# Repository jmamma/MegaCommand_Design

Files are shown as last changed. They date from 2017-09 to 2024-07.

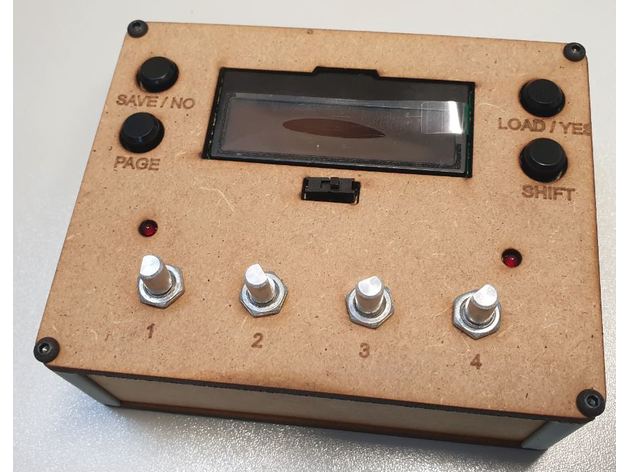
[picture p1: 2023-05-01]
Enclosure/MegaCommand_DIY/Router Design/images/20221028_100851.jpg

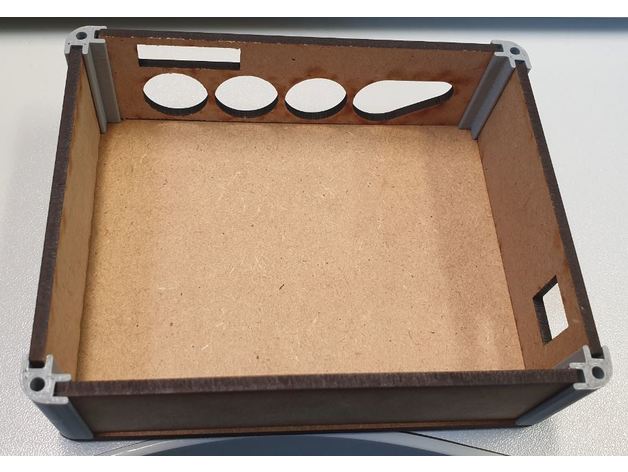
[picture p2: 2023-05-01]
Enclosure/MegaCommand_DIY/Router Design/images/20221028_100230.jpg

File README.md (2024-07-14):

# MegaCommand

## Description:

The MegaCommand is an open-source MIDI controller that runs the MCL firmware for use with the Elektron Machinedrum.
It is is based around the Arduino Mega 2560.

The printed cicuit board is a through-hole design (no SMD soldering skills required). 

* 4 x MIDI ports (2 in, 2 out)
* 4 x Rotary Encoders + Push button
* 4 x Buttons
* 1 x OLED display
* SD Card
* 128KBytes of SRAM (0-63KB accessible natively, 64-128KB accessible with bank selection)
* 2 x 10pin Expansion ports

Stack is 8KB in size. 
56KB of SRAM reserved for global objects, variables. (bank switchable)

The MCL respository contains the software component of this project.
https://github.com/jmamma/MCL

## Project Status:

Board revision: 1_0_2a12

__ALL INFORMATION BELOW IS PROVIDED AS A CONVENIENCE AND COULD BE SUBJECT TO ERROR OR CHANGE.__

## Bill of Materials:

1.0.2a:
https://github.com/jmamma/MegaCommand_Design/blob/master/1_0_2/bill_of_materials

## Display

OLED 128x32, it uses the SPI bus.

Important: OLED display requires resistor position changes to enable SPI mode as per adafruit documentation 
https://learn.adafruit.com/2-3-monochrome-128x32-oled-display-module/assembly-1):

## PCB Fabrication:

You can easily get your own PCBs made.

[PCBWay.com fabrication options](https://github.com/jmamma/MegaCommand_Design/blob/master/pcb_fabrication_preferences.jpg)

Gerber files (pcb layout diagrams used for fabrication) are included in the ./gerber/ directory above.

Download gerbers and submit to PCB manufacturer.

Circuit Schematic and Board Layout is present in Eagle files.

## Enclosure:

1.0.2a:

The enclosure can be 3D printed. The design files and variations are located in:

https://github.com/jmamma/MegaCommand_Design/tree/master/Enclosure/OLED/3D

Optionally print 4 spacers and superglue to the screw holes on the OLED to ease
installation of the screen at the proper height.

## Build Instructions

The build is organised in to multiple stages. You must follow the order sequentially.
At the end of each stage there is a test checkpoint. It is important that you perform these tests to ensure
each stage is working before proceeding to the next, failing to do so will make troubleshooting any problems much harder.

```
VERIFY CHIP ORIENTATION BEFORE SOLDERING.

OLED display must be installed last.

Take care in making sure the ICs are inserted the correct way around.

## Build Order: 

  1. ICS: RAM, Octal Latch, Shift Registers
  2. Arduino male headers. 
  3. Capacitors. (Make sure the 220uF electrolytic cap fits when the arduino is connected)
                 (10uF +ve terminal is soldered to pad closest to SD card holder.
                 
TEST POINT: Run the SRAM firmware test.

  4. MEC switches (Make sure these sit completely flush with the board and are not leaning to one side)
  5. Resistor arrays
  6. Encoders (Make sure these sit completely flush with the board and are not leaning to one side)  
  
TEST POINT: Run the button and encoder test firmware.
  7. ICS: MIDI Optocouplers. 
  8. Resistors + diodes
  9. MIDI DIN ports.
 
TEST POINT: Run the MIDIPort test firmware.

 10. Power Jack (+9V tip)
 11. Yamaichi SD card holder.
     
TEST POINT: Insert SD Card, Run the SDCARD test firmware
 
OLED Display:
 12. Oled display requires correct resistor poisiton in order to be configured for SPI mode. (See documentation above to confirm the resistor placement)
 13. Male header to be soldered to OLED board. Header is then soldered on to MegaCommand PCB. The height of the OLED display is important. The distance between the mainboard pcb, and the bottom on the OLED pcb should be 5mm when soldered.
 
 14. LEDs (+ anode pin nearest to the bottom of the board for both LEDs. ). When soldered, the tip of the LED should measure 11mm above mainboard pcb.
 
 15. Power switch. (optional, you can solder a short between the two right most pins on EG1212B  
 
 Expansion Headers:
 
 16. These are short 5mm headers. It might not be possible to buy them at the right length so you'll need to cut them down to 10 pin.
 
TEST POINT: Run the LCD and LED test firmware.

## Important

OLED Display must be installed last.

5) To install the male headers that connect to the MegaCommand to the ArduinoMega, insert the headers in to the ArduinoMega then solder with the arduino attached to the headers. This will ensure perfect alignment.
```

## Firmware

Once you've built a MegaCommand you can upload the latest version of the  MCL firmware located here: 
https://github.com/jmamma/MCL/releases

If you're familiar with coding you can write sketches within the Arduino IDE to test the hardware and run custom firmwware.
Before you start coding you need to decide which core you are going to use.

## Arduino Cores
In ArduinoIDE, a Core is a collection of initialisation functions and associated libraries, used for configuring the underlying hardware; it is analogous to an Operating System kernel.

The cores availabile in the Arduino IDE are listed under Tools -> Boards.

Arduino Mega or Mega 2560:

This is the standard core that comes installed default with the Arduino IDE. If you use this core with the MegaCommand you can program the MegaCommand like an ordinary arduino shield. The built in arduino functions can be used to control the hardware using the pin assignement detailed below.

MCL Core:

This was built on top of Manuel Odendahl's core for the MiniCommand.
By using this core you can take advantage of the powerful MIDI libraries and GUI functionality.

For example, the MegaCommand core is necessary for running the MCL firmware, and controlling the Elektron instrument range.

### Installing the MCL core.
(Instructions for OSX, should be similar for Windows)

1) Download the Arduino IDE https://www.arduino.cc/en/Main/Software (1.8.5 tested)

2) Get the MIDICtrl library and MegaCommand Core (same repo):
```
   cd /Applications/Arduino.app/Contents/Java/hardware/
   git clone https://github.com/jmamma/MCL
```
### Selecting the Core

1) Open the Arduino IDE, Under the Tools menu, select the core you wish to use from the "Board:" menu

The default Arduino core is named "Arduino/Genuino Mega or Mega 2560"

The MegaCommand core will be listed at the bottom. 

## MegaCommand vs MiniCommand

The MegaCommand shield was designed to be backwards compatible with the original MiniCommand hardware. 

However, there are notable differences between the two systems, including new pin assignments which must be taken account for when using the original MidiCtrl libraries.

The original MiniCommand used the ATMega64 microprocessor whilst the MegaCommand Shield is built on top of ArduinoMega which uses the ATMega2560 processor. The ATMega2560 shares most of the IO functionality of the ATMega64 but has additional pins, and a different pin-to-port layout.

The MegaCommand Shield accesses the ATMega2560 processor on board the ArduinoMega through the exposed headers, not all pins on the ATMega2560 are exposed through this Arduino interface.

Incorporating the differences between both processors and subsequent pin availability the following pin assignment has been made as the best possible substitutes for the original hardware layout.

```
4 Midi Ports vs 3
256k ROM vs 64K
USB vs No USB

--

MegaCommand pin changes from original MiniCommand are as followed:

MicroSD board:

CS = PB0

SRAM

BankSel = PL6

Key Scanning (Shift Register Circuit):

PL0 = OUT
PL1 = SHIFT
PL2 = CLK

HD44780 LCD Circuit:

E = PL4
R/S = PL3

LEDs:

PE5 = LED0
PE4 = LED1

MIDI:

TXD0 and RXD0 (USART0) are reserved for Arduino USB interface.

Therefore we shift midi ports by 1.

MIDI Port 1:

RXD1 = MIDI Port 1 IN.
TXD1 = MIDI Port 1 OUT

Midi Port 2:

RXD2 = MIDI Port 2 IN
TXD2 = MIDI Port 2 OUT ( New port, not available on original Minicommand)
```

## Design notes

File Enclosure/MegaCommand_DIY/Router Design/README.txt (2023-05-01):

Megacommand Case by Pabloantxon on Thingiverse: https://www.thingiverse.com/thing:5591808

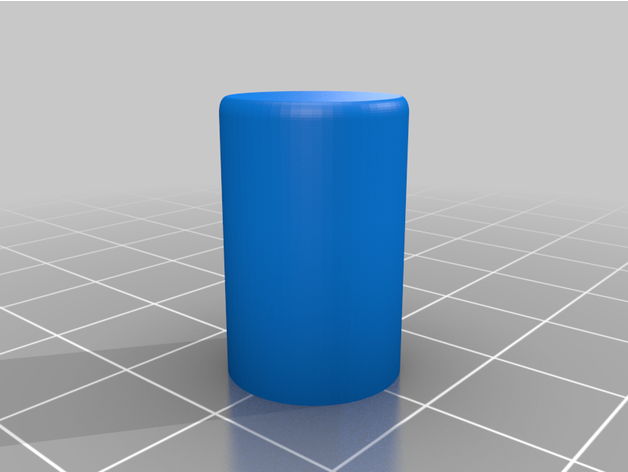
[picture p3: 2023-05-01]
Enclosure/MegaCommand_DIY/Router Design/images/knob.png

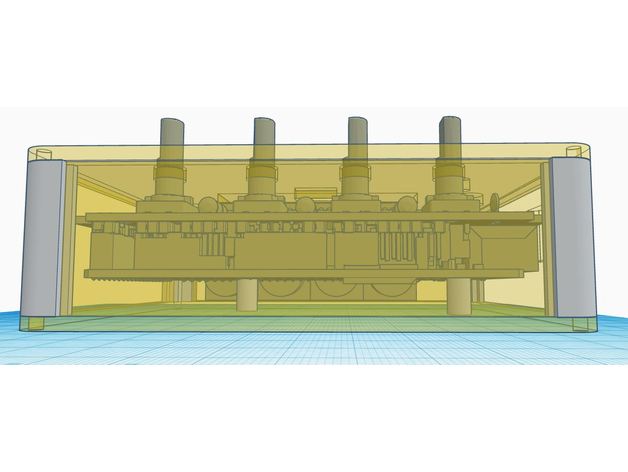
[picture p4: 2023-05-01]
Enclosure/MegaCommand_DIY/Router Design/images/3D3.JPG

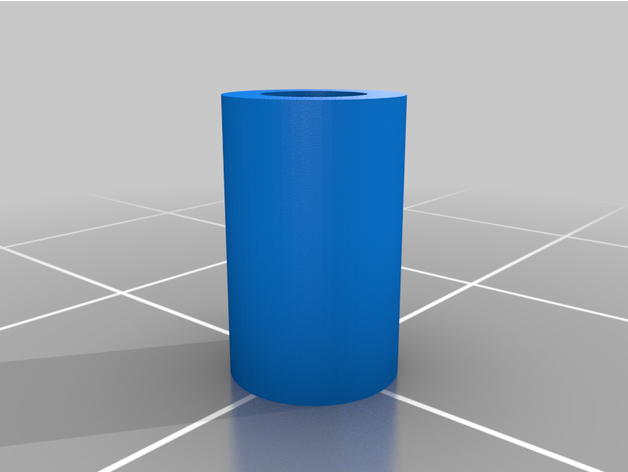
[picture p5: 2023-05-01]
Enclosure/MegaCommand_DIY/Router Design/images/ArduinoStand.png

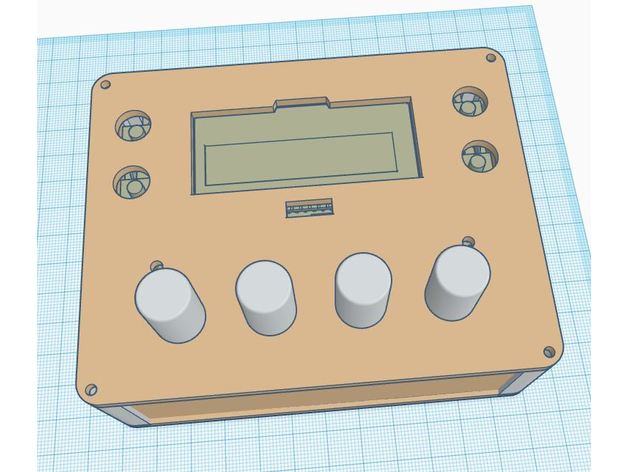
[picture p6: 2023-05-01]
Enclosure/MegaCommand_DIY/Router Design/images/3D4.JPG

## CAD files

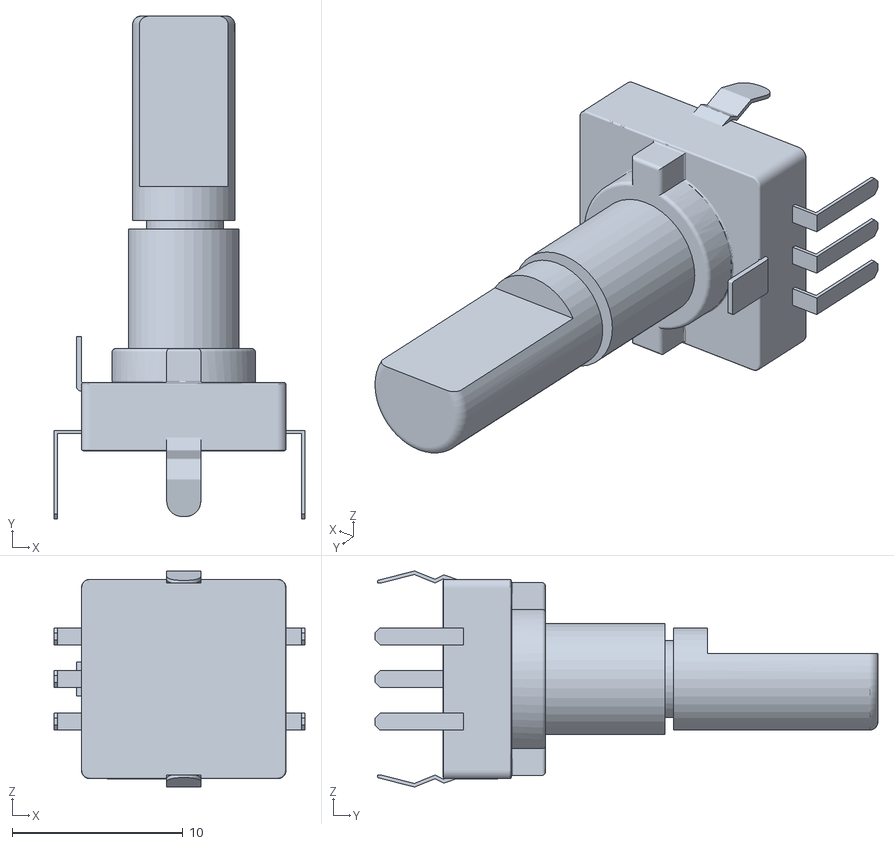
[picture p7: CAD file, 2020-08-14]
Assembly_Models/alps_encoder.STL
14.7 x 29.5 x 12.7

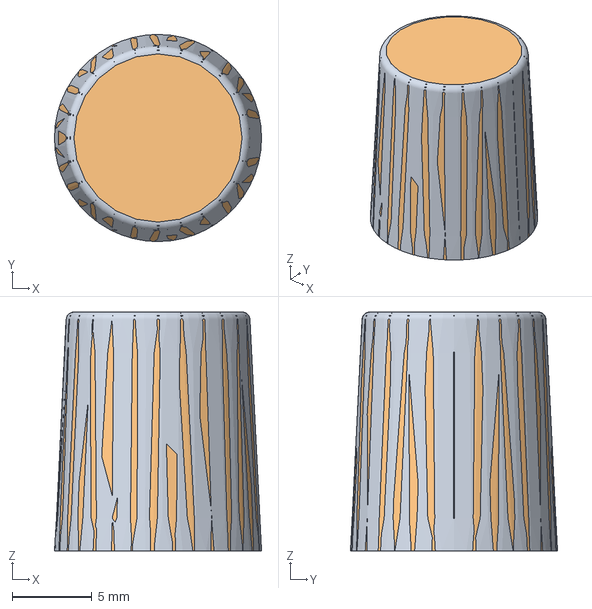
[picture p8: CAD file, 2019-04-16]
Enclosure/Encoders/encoder.FCStd
13.0 x 13.0 x 15.0 mm
Fillet (Meshed)

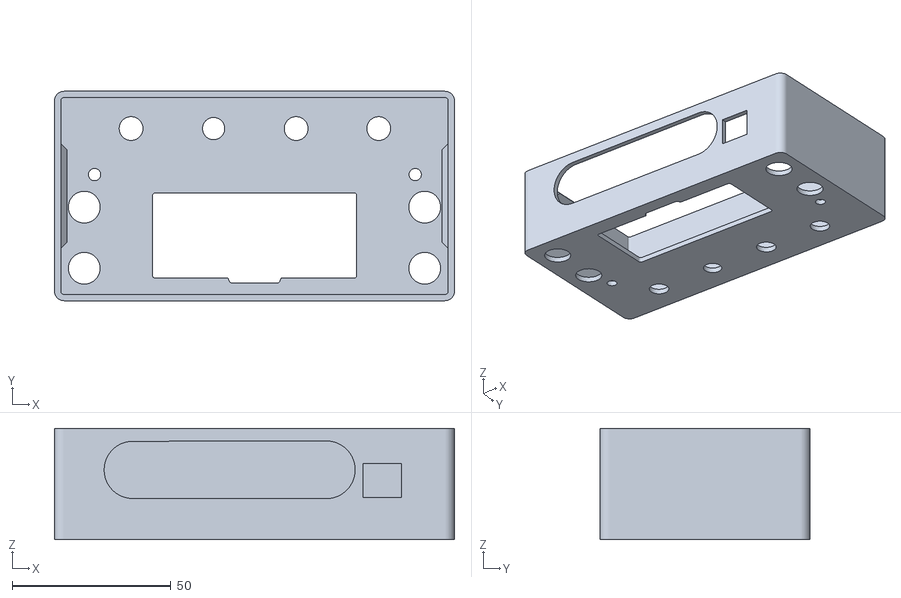
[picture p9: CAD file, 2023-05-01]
Enclosure/MegaCMD/megacmd_body.stl
126.0 x 66.0 x 35.0

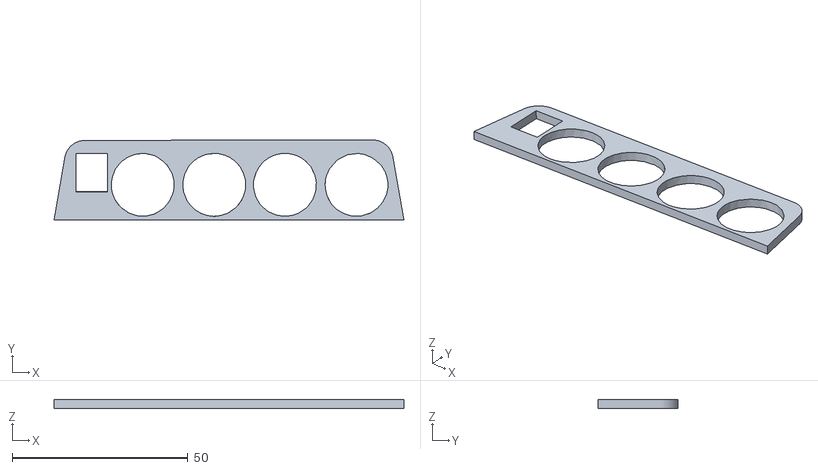
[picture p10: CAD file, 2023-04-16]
Enclosure/MegaCommand_DIY/3D/MG_panel.stl
99.7 x 22.8 x 2.50

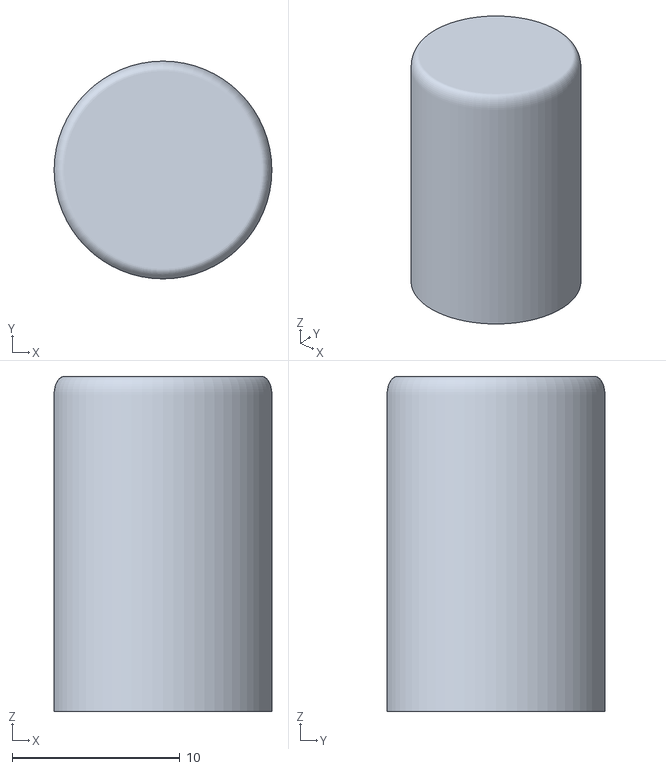
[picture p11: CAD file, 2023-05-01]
Enclosure/MegaCommand_DIY/Router Design/files/knob.stl
13.0 x 13.0 x 20.0

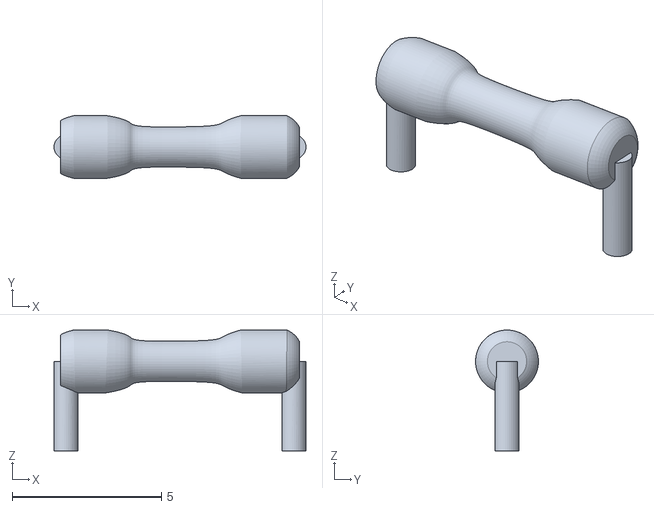
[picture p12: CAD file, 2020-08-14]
Assembly_Models/0207_7_0207_7.STL
8.43 x 2.10 x 4.05

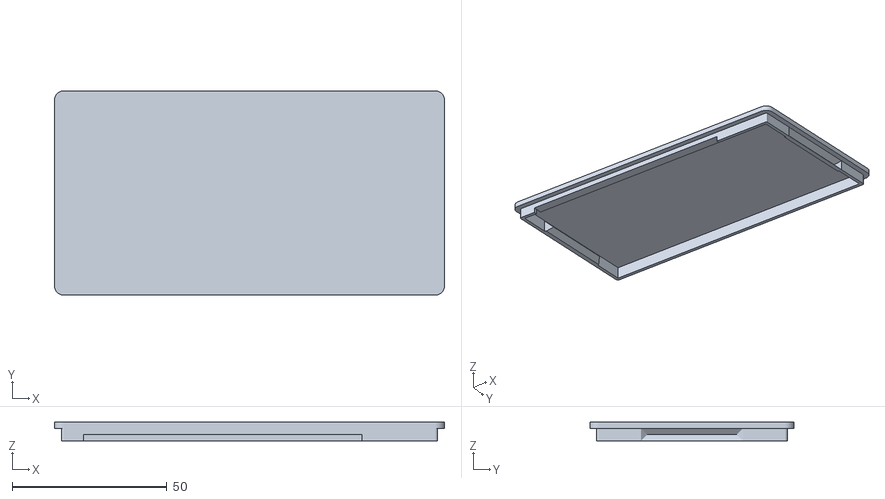
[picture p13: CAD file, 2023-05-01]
Enclosure/MegaCMD/megacmd_lid.stl
126.0 x 66.0 x 6.00

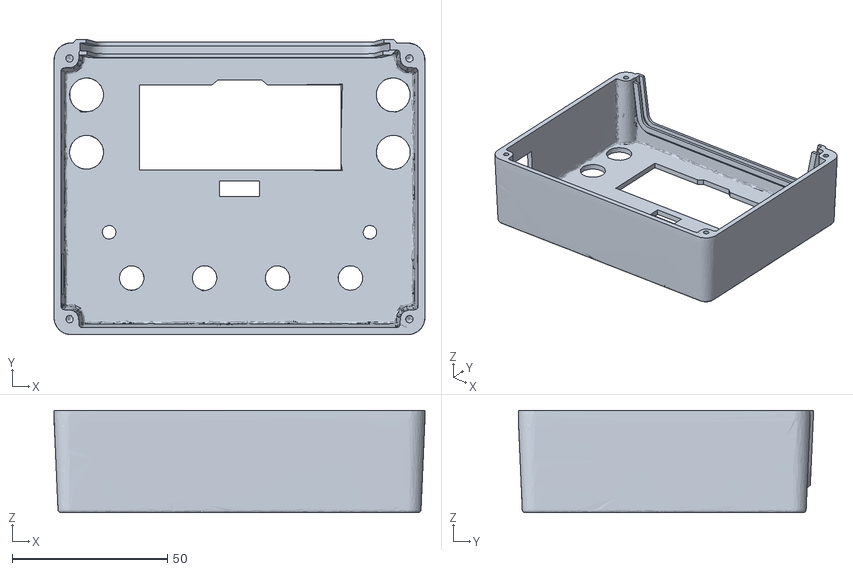
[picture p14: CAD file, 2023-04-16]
Enclosure/MegaCommand_DIY/3D/MG_body.stl
119.5 x 95.2 x 33.0

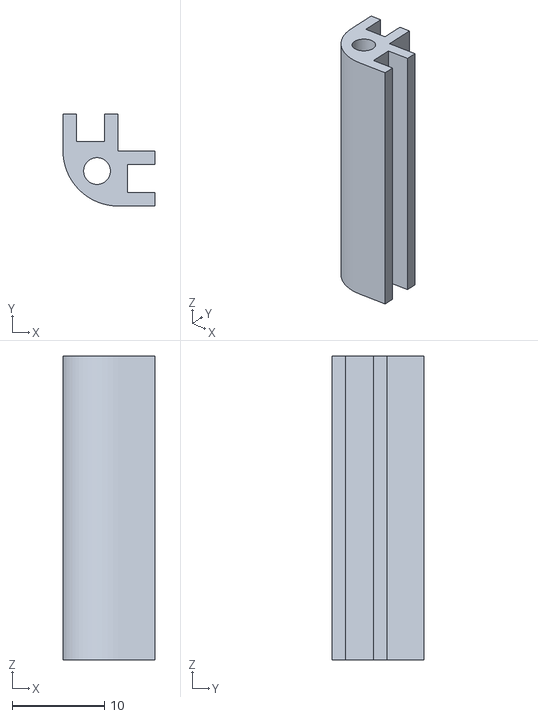
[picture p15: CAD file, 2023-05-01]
Enclosure/MegaCommand_DIY/Router Design/files/BoxCorner.stl
10.0 x 10.0 x 33.0

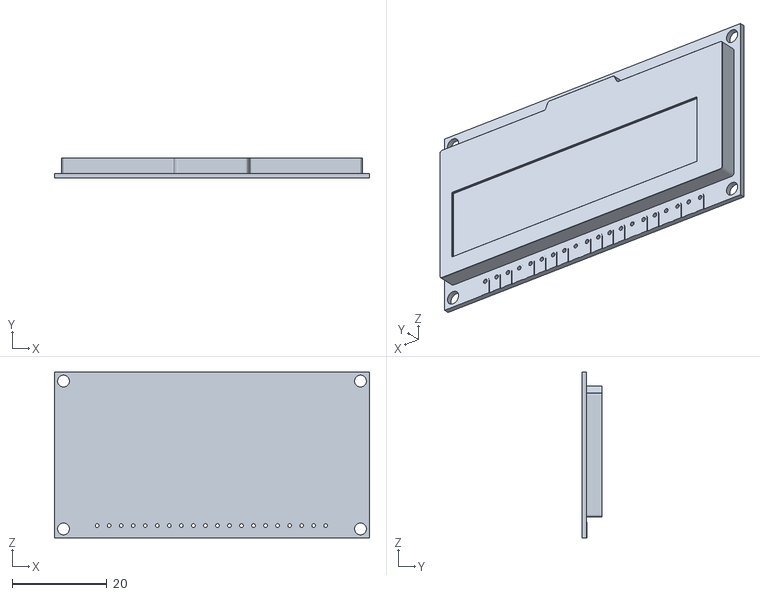
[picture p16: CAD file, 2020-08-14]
Assembly_Models/oled_2.STL
66.5 x 4.30 x 35.0

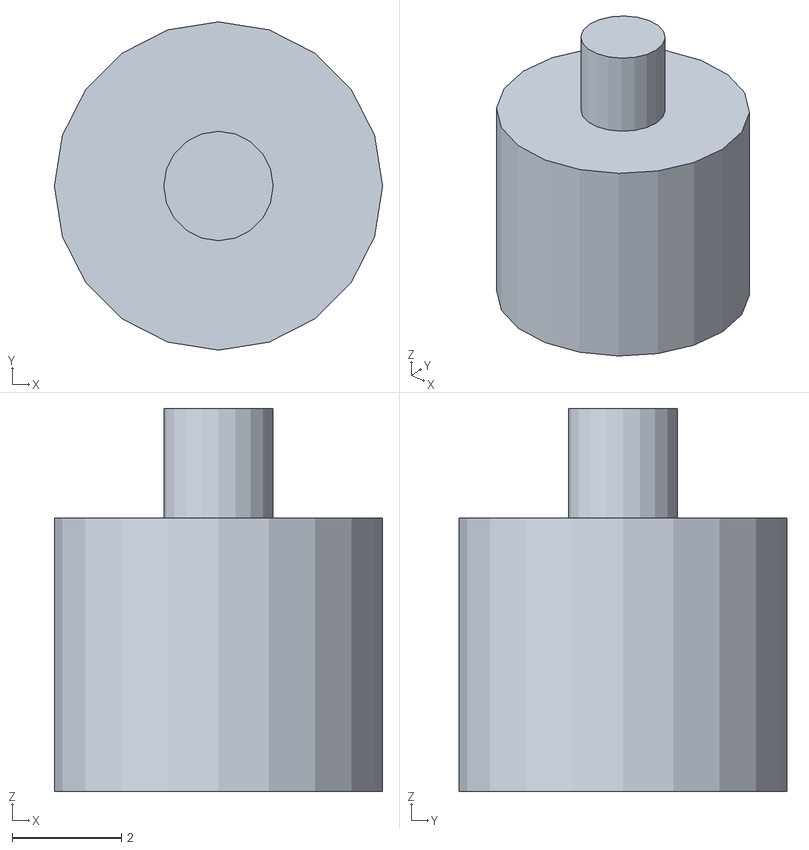
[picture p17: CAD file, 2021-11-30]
Enclosure/MegaCommand_DIY/3D/oled_spacer.stl
6.00 x 6.00 x 7.00

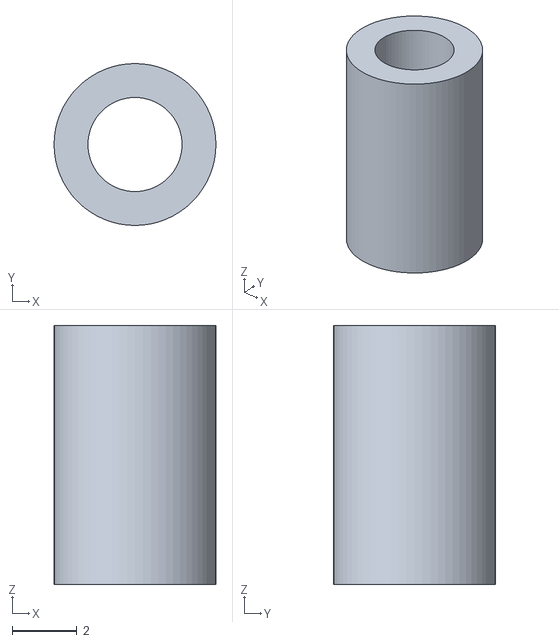
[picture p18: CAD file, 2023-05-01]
Enclosure/MegaCommand_DIY/Router Design/files/ArduinoStand.stl
5.00 x 5.00 x 8.00

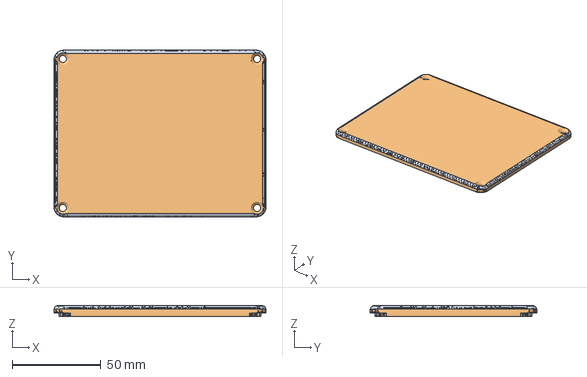
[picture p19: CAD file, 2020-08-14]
Enclosure/MegaCommand_DIY/3D/megacommand_lid_1_0_2d-tall.FCStd
119.5 x 94.0 x 6.00 mm
Connect
Connect (Meshed)

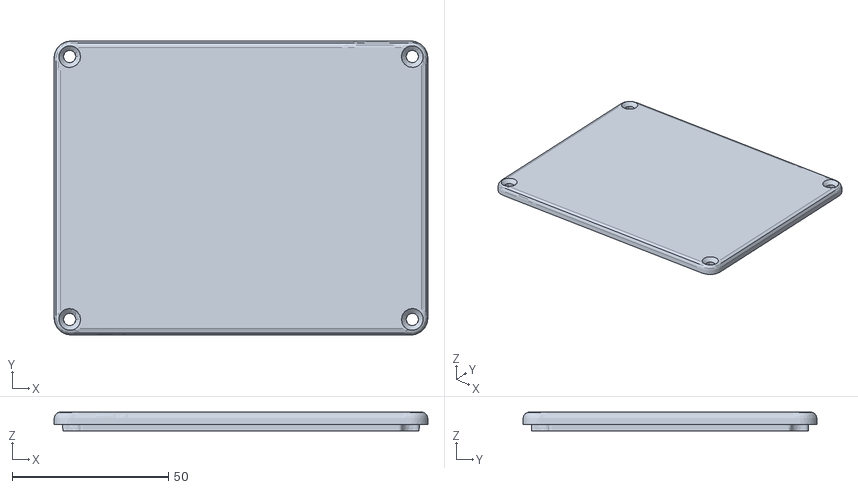
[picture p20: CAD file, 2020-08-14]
Enclosure/MegaCommand_DIY/3D/megacommand_lid_1_0_2d-tall_small_rise.stl
119.5 x 94.0 x 6.00

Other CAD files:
Enclosure/Encoders/encoder.stl

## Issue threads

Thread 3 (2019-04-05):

A little Bug in OLED enclosure model.

onoma2, 2019-04-05:
Hello, there are not enough data in STL model for 3d printing the case.

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

jmamma, 2019-04-05:
Hey Max,

I am assembling my 3d printer this weekend. I will investigate once it's set up.

Do you know the specific issue?

Cheers,

- Justin

onoma2, 2019-04-05:
Missing points on the mesh. Please see screenshot attached.

jmamma, 2019-06-01:
This was resolved. New model files uploaded some time ago

Closed 2019-06-01.

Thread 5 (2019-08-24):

Alternative Chassis Design (migrated)

yatli, 2019-08-24:
I'm working on a metal chassis design.

Basically, I'd like to make it low-cost, durable and mountable. The current design consists of two parts, each can be produced with sheetmetal (304, 6061 etc.)

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

Potential problems:

The screw tap hole "ears" are less than optimal. May consider bend the whole edge instead of cutting those 6 ears.
Screen height?
No power switch hole...

yatli, 2019-08-24:
The first batch has arrived. Lots of bugs, but I managed to fit it in:

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

yatli, 2019-08-24:
== Problems ==

- [ ] The OLED Display window misaligns. It should be ~1mm left to the current position.
- [ ] The OLED Display window should be higher. Currently it mates very tightly with the metal case of the display.
- [ ] The left LED should be ~1mm left to the current position.
- [ ] Encoder through holes should be larger.
- [ ] Mount points is a joke -- one of them projects right onto the usb port!
- [ ] Key switch through holes should be larger.

yatli, 2019-08-24:
The photo is different from the original design that the chassis tap drills are now all on the base plate.
The panel plate "envelopes" the base plate now.
The sheet metal flanges are also simplified to bring down the cost.
I've got 2 pairs at RMB 150 each.

yatli, 2019-08-24:
Caveats:

1. Put insulation washers between the board and the copper standoffs. Otherwise it will short some pins.

2. Cut the washers so that the profile stays inside the pcb area:

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

3. Tape the back of the panel around the OLED window. Otherwise it will short the display pins after assembly.

jmamma, 2019-08-27:
Heavy Duty.

yatli, 2019-08-27:
Yeah.
Full Metal Jacket.

yatli, 2019-11-08:
Having a metal chasis is a bad idea. I almost fried something in MD when the rack mount screw contact with the MC metal chasis -- MD GND is -5V to USB GND, and a short of the two results in MD voltage dropping to 4V, which is very dangerous.

Closed 2019-11-08.

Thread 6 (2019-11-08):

MegaCommand peripheral bus

yatli, 2019-11-08:
I propose we standardize the extension port communication protocol.

These are the pins exposed through the two expansion ports:

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

- Power
- Two serial ports (UART0, UART3)
- SPI MOSI
- I2c, or SOFT-SPI (can be MISO)
- GPIO

The two serial ports can enable a daisy chain configuration, and multiple expansion parts can be mix-and-matched.

UART0 is configured as the master, and keeps sending out active sensing commands at intervals.
UART3 is configured as the slave. When active sensing command is received, it reports back the presence.

The hardware SPI doesn't expose MISO and is not suitable as a bus. The I2c is only present on one side of the board, and harder to program. So they are better treated as private expansion ports only visible to the current host.

jmamma, 2019-11-08:
Yeah, I think this sums up what I was aiming for.

For a "light weight" + low power expansion board without it's own CPU/, you can use one of the digital pins to supply, 5V power @ 40mA (MAX).

yatli, 2019-11-08:
There should be a mechanism for identifying a MCU-less expansion.
Some kind of ADC or digital level encoding would do.

And then we can number our expansion parts, e.g. TRIGGERS-1, KEYBOARD-2, OPTICSFADER-3 etc.

jmamma, 2019-11-08:
Yeah I had that Idea as well. Some binary sequence that could be read back. The CLK, SHIFT, LATCH was supposed to facilitate this in addition to reading additional switch input.

yatli, 2019-11-08:
A host with MCU, during presence reporting, should also reveal the private resources that it is willing to expose.

For example, if we build a sampler module with additional pads, it can decide whether to show/hide the resource to the master.

Then, a chain-of-responsibility model can be applied so we decide who takes that resource by their priorities.

jmamma, 2019-11-08:
>Then, a chain-of-responsibility model can be applied so we decide who takes that resource by their priorities.

How many MCs are you planning to link together 😉

yatli, 2019-11-08:
That's probably overengineering at the moment. XD

But I do have some ideas.  One for MNM and OT, and another for Reason Remote (the Reason sequencer is just not as good).

yatli, 2019-11-11:
If we re-program the 16u2 on the arduino board, we can make a USB-MIDI interface. As 16u2 is connected to UART0, it can only be the rightmost MC in the chain.

yatli, 2019-11-11:
🤔🤔🤔 getting a bit curious what'll happen if I hook up a USB keyboard.
vim key-bindings for step editing?

jmamma, 2019-11-11:
Yes thought about makingn it class compliant.
FYI: Some of the chinese boards dont have the 16u2.

Also if the 16u2 is re-programmed then it cant be used to upload firmwares anymore.
So you'd probably want to write a new bootloader that uploads firmware via MIDI, like the Minicommand.

yatli, 2019-11-11:
There's a custom firmware that functions as the arduino programmer only when a jumper is added to the 16u2 ISP headers

jmamma, 2019-11-11:
didnt know that!

yatli, 2019-11-11:
This one: https://github.com/kuwatay/mocolufa

jmamma, 2019-11-11:
Ah, very cool.

Can the Mega/16U2 function as a USB host for attaching peripheral USB devices?

yatli, 2019-11-11:
> Can the Mega/16U2 function as a USB host for attaching peripheral USB devices?

I was really hoping for that, but after some searching it seems 16u2 is a usb device, not host

yatli, 2019-11-11:
A USB host chip + arduino nano should do it nicely. Then we can use the bus protocol to probe its capabilities.

jmamma, 2019-11-11:
> > Can the Mega/16U2 function as a USB host for attaching peripheral USB devices?
>
> I was really hoping for that, but after some searching it seems 16u2 is a usb device, not host

Yeah that's what I thought.

yatli, 2019-11-12:
> FYI: Some of the chinese boards dont have the 16u2.

Last night I checked my arduino reps, no little square chips anywhere 🤦‍♂️

micabeza, 2020-04-20:
not sure where to post my question, ut i figured here is better than the electron forum.
I'm kinda a noob at all this coding/building, but i have a couple questions as I'm looking to attempt to use the expansion ports.
1) is there anywhere i can get some documentation how you are reading values from the MD, particularly trigger buttons and encoder values?
2) is there a place best suited to drop in code?  i looked at the source code files, and for a noob, they are a bit overwhelming right now....

please let me know if theres a better place to post these questions.
great work so far!

jmamma, 2020-04-20:
Software side of the project is.

https://github.com/jmamma/MIDICtrl20_MegaCommand/

You can submit software related questions as new issues there ^.

Cheers,

- Justin.

yatli, 2020-08-14:
The ATMega USART has a multiprocessor mode so that one can connect a master MCU to multiple slave MCUs on a single UART.
It's like RS-485 for free :p

jmamma, 2020-08-14:
EXP ports wouldn't work for this configuration though? As the UART RX on left exp port is not mirror'd on right exp port.

jmamma, 2020-08-14:
EXP ports wouldn't work for this configuration though? As the UART RX on left exp port is not mirror'd on right exp port.

yatli, 2020-08-14:
Will need a breakout board to connect more than two together, anyway

yatli, 2020-08-14:
In this way the processors can be organized more efficiently than a daisy chain. Multiple slave devices (USB host, WIFI etc.) are connected to the master directly. This prevents, for example, TCP data to flow through a mouse :D

Slave devices additionally use one pin to indicate send request, and with a parallel to serial shifter, the master can get the requests and arbitrate.

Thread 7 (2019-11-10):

Board file: Arduino male headers base profile should be printed on the other side

yatli, 2019-11-10:
The second time I tooke an empty board, solder all the pins only to find I've done it on the wrong side (facepalm)

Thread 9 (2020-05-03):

sram test fails

frnktrpz, 2020-05-03:
Hi, opening this issue after asking for help over at elektronauts after running into some issues as a possible consequence of the (classic?) mistake of soldering the oled before the sd-card holder.

Before desoldering the oled screen all test firmwares ran successfully. After desoldering the sram test fails instantly, led, sd-card and encoder/button tests all still successful. Ram test gives the following error:

>  Megank0 mismatch
2200
MegaCommand SRAM Test
2200
SRAM Test Failed bank0 mismatch
2200

Tried several times, tried reseating the board just in case but the same error occurs.
Before replacing the ram it would be great if anyone could shed any light on other possible causes than a damaged/faulty ram chip.

Here are pictures of my build:
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

jmamma, 2020-05-03:
Can you take a clearer version of the bottom side of the board. i want to see the traces around the sram chip clearly

thanks

frnktrpz, 2020-05-03:
Hope these are more useful:

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

jmamma, 2020-05-03:
I get the same test error when I attempt to run the SRAM test with the arduino disconnected from the main board.

This means theres a connectivity problem somewhere.

```
Mest
2200

Failed bank0 zero reading
2200
MegaCommand SRAM Test
2200

Failed bank0 zero reading
2200
```

1)

For sanity, reconnect the Arduino and try again. Check that all the male header pins are aligned correctly with the Arduino when attaching it.

2)

Was the SRAM test working prior to the display problems?

3)

Can you make sure that there are no short circuits between solder joints. I see a few spots where there is a little bit of solder that might be causing a short between two unrelated pads.

4)

Do you own a multimeter?

Check that the SRAM chip is getting 5V. Pin32 connected to capacitor C4.
https://docs.rs-online.com/6fa1/0900766b8139de13.pdf

and check GND.

5)

The next step would be to verify the traces between the SRAM chip and the double row header. start with Power and GND and then work through the other traces. Keep a checklist.

--

Troubleshooting may seem daunting, but it's a digital circuit and we can number down the possibilities by working systematically.

frnktrpz, 2020-05-03:
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

Thank you for the amazing support, really appreciate it!
1.
Headers appear to be aligned correctly, reseating the board doesn't seem to make a difference.
2.
Sram test was successful before desoldering the oled screen.
3.
Cleaning the board seems to have helped a bit as the test now runs for for a while before giving the error:
>2A00
SRAM Test Failed bank0 mismatch
2A00

Test seems to fail at the same point each time.
4.
If I measure voltage between the large GND on the MC pcb and pin 32 on the sram my multimeter indicates a short.
5.
I installed autodesk so I can systematically start working through the various test points. Will probably take me a while as I'm not used yet to navigating schematics.

jmamma, 2020-05-03:
I can send you a screenshot of the top and bottom board traces.

frnktrpz, 2020-05-03:
That would be great, thanks.

jmamma, 2020-05-03:
[megacommand_1_0_2a12_top_bottom.pdf](https://github.com/jmamma/MegaCommand_Design/files/4570198/megacommand_1_0_2a12_top_bottom.pdf)

Viewed from top.

RED: top traces
BLUE: bottom traces.

jmamma, 2020-05-03:
Can you measure voltage across the double header pins GND and 5V.

frnktrpz, 2020-05-03:
I get around 4.5V reading across.

jmamma, 2020-05-03:
I read 4.5V as well.

Now check GND (from double pin header) to the supply voltage of each chip

jmamma, 2020-05-03:
> "edit;
> Gave the board another clean and instantly got a bank0 read error, reconnected the usb cable and back to the initial bank0 mismatch error.
> Not sure if relevant."

can't really make any conclusions at this stage.

If measuring voltages doesn't reveal anything unusual. Disconnect the arduino and start looking at the traces.

It's getting late here. So i will check in the morning to see your progress.

frnktrpz, 2020-05-03:
> I read 4.5V as well.
>
> Now check GND (from double pin header) to the supply voltage of each chip

Consistently getting around 4.7 volts across. Except for the level shifter which shows around 3.3V.

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

Ok, thanks again! Should keep me busy for a while. Have good night.

frnktrpz, 2020-05-04:
I checked continuity for all the traces to/from the ram ic with my multimeter and was not able to find any fault. Didn't measure resistance, just checked the traces.
All firmware tests besides the ram test (and the oled test, am unable to test now) run successfully. Is it safe to assume that the ram chip needs to be replaced or am I jumping the gun?

jmamma, 2020-05-05:
My only other suggestion would be to re-flow the solder joints on the SRAM and octal latch. This would rule out a cold solder joint...

Another less scientific test would be to apply constant physical pressure to SRAM chip (with your thumb) and re-run the SRAM test. See if the test proceeds beyond 0x2200. This may reveal an intermittent connection...

Just be weary that desoldering the SRAM will be harder than removing the OLED. the pads are much smaller, and there is a risk of stripping them from the board.

yatli, 2020-05-05:
@frnktrpz also check the bank selection pin (PIN43)

You can enable the debug information in the test firmware, around line 57: https://github.com/jmamma/MegaCommand_Design/blob/3d7930fea5477b9c5ef57f928413bf8be208d8a9/TestFirmwares/megacommand_sram_test/megacommand_sram_test.ino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

Uncomment these, and see if bank1 reading is correct but bank0 is not.

jmamma, 2020-05-05:
@yatli If bank select is not working, then it should read/write to the same bank.

Previously he was getting as far as 2A00

which is 2560 bytes.. I thought this may be indicative of an address line fault. But it doesn't line up with the addressing scheme.( It's been a while since I've looked at this. Maybe my interpretation is wrong.)

2^11 = 2048
2^10 = 1024
2^9 = 512

yatli, 2020-05-05:
Ah, yes.
But I still recommend printing out the values -- if we get the same wrong value from both banks it means something (I'm not sure what it is yet)

jmamma, 2020-05-05:
SRAM Test Failed bank0 mismatc

Yeah he's getting a mismatch. Which means the value read from bank 1 doesn't match the value read from bank 0.

A static address line fault wouldn't cause this.
A static bank select  line fault wouldn't cause this.

yatli, 2020-05-05:
The test FW doesn't compare bank1 read with bank0 read -- it compares both with the source random number, and when bank0 check fails, it doesn't report what's happening on bank1, just exit.

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

Hypothesis: 2^11 and 2^9 pins shorted?

jmamma, 2020-05-05:
https://andybrown.me.uk/2011/08/28/512kb-sram-expansion-for-the-arduino-mega-design/

reference ^

jmamma, 2020-05-05:
``` When choosing a latch we must ensure that it is fast enough to cope with the 16Mhz core clock of the Arduino. 74HC series latches are too slow. The datasheet recommends that we use the 74AHC series. ```

That's interesting.

jmamma, 2020-05-05:
@yatli what type of latch are you using.

I'm running 74AHC series.

yatli, 2020-05-05:
I've got `SN74HC573N`
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
jmamma, 2020-05-06:
Can you verify VSS and CE2 are 5V.

and VSS is GND

Measure from the top side of the boards on the legs of the chip.

frnktrpz, 2020-05-06:
Around 4.4V on both of those, measuring resistance between VSS and GND on the pcb gives something like 00.2 ohm.

Have to go back to work in 5 hours so unfortunately won't be able to do any further checks until tomorrow.

jmamma, 2020-05-06:
The SRAM test attempts to write a non zero value to the SRAM and then read it back.
It does this on both banks, and across all available memory addresses, starting at 0x2200.

If the read is zero, then the test fails.

```
2200
114
0
0
```

In your test, it tried to write the value 114 to memory position 0x2200 (the first memory address in the SRAM). When it reads it back it reads 0.

This means the data lines coming from the SRAM chip are all low.

114 in binary =  0b1110010
At least 4 of the data lines should be high.

--

SRAM Chip enable and source voltage are correct.

Evidence suggests the SRAM chip is not working.

@yatli this is my conclusion. Do you have anything to add?

jmamma, 2020-05-06:
Triple check WE and OE  (write enable, read enable) line from SRAM and arduino double header.

yatli, 2020-05-06:
One more thing to add, also check WE and RESET for 573. If reset is shorted, it will always give zero.

jmamma, 2020-05-06:
output of 573 is only used for address lines. not data. so I dont suspect this is the fault.

frnktrpz, 2020-05-06:
> Triple check WE and OE (write enable, read enable) lines from SRAM and arduino double header.

Cheers. Just got ready to check the traces one more time. Keep getting slightly different results each time I run the test, never gets very far but there's variance every time. Will check back in after this.
Thanks again, really appreciate the support from you as well as yatli.

frnktrpz, 2020-05-07:
Ok, it seems there is some bad connection going on after all.
I re-checked the traces, each time a suspect connection came up it was either my poor handling of the probes or a topographical error and double/triple checking verified the connection.

However one thing that I hadn't yet checked (for which I apologize, it didn't occur to me initially) were the double row headers between the Arduino and the MC board. A couple of the PA pins showed a way higher resistance value than the others. I used compressed air on the female headers and cleaned the pins with some alcohol.
After reconnecting, the first 3 times the ram test results were the same as before. The fourth time it actually started going, but kept running way beyond 5 minutes and lines like this showed up:
>22
CA78
16
16
16
CA79
86
86
86
CA7A

Stopped the test after 15 minutes or so, reconnected the usb cable, ran the test again and it passed. Just ran it successfully for the second time. I'll run it again a couple of times tomorrow to be sure before re-soldering the oled screen...

jmamma, 2020-05-07:
Great work.

> I'll run it again a couple of times tomorrow to be sure before re-soldering the oled screen

Best to be absolutely certain SRAM is working before moving on to the OLED.

Maybe give those pins a good soak in Isopropyl if you haven't already.
You could reflow the double header solder joints as well, if you suspect cold solder.

frnktrpz, 2020-05-08:
Reflowed some of the solderpoints on the double header and gave the board one more solid clean today after the ram test failing again this morning. After letting the board dry for a few hours I decided to solder a female header for the oled rather than soldering it on directly as I wasn't sure it was still in working condition after having gone through my desoldering treatment. Reconnected the board, ran the ramtest again, uploaded the firmware and:
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

Thanks again for the support jmamma and yatli, troubleshooting this with your help has been a great learning experience for me. Shoutout to micabeza as well for reaching out and offering help. Hope I'll be able to contribute a bit in the future.
Cheers!

jmamma, 2020-05-09:
Looking good. Well done for persevering.

albadort76, 2021-05-03:
Hi, having a look on your pictures of the thread, I think your C7 electrolytic 10uf capacitor is not in the good orientation.

frnktrpz, 2021-09-19:
> Hi, having a look on your pictures of the thread, I think your C7 electrolytic 10uf capacitor is not in the good orientation.

Haha, you are absolutely right. Didn't notice this until a few weeks ago while building a fresh MC because I wanted one that didn't have the oled screen misaligned because I decided to put it in some headers after my initial mishap. Regardless the MC operated normally for over a year. That's some solid circuit design.

Sorry for necro'ing but I'm glad to be able to share this :-D

Closed 2023-02-24.

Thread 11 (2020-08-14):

Enclosure & knobs, {tall,short}/material recommendation?

yatli, 2020-08-14:
I'd like to print a few official cases and knobs, any recommendations here? I see there are two versions (tall/short).
Also, very cool to see the knob getting modeled! Wonder if I could print rubber-like knobs?

jmamma, 2020-08-14:
You want to print the Tall enclosure.

_The short version is the same height as the original minicommand case but requires shaving off around 5mm of plastic off the DIN ports._

I have flexible filament. I haven't tried printing encoders using it though.

jmamma, 2020-08-14:
You want to print the Tall enclosure.

_The short version is the same height as the original minicommand case but requires shaving off around 5mm of plastic off the DIN ports._

I have flexible filament. I haven't tried printing encoders using it though.

yatli, 2020-08-14:
Another question :p

How do I lock the board to the enclosure? I see 4 through holes on the lid but it's supposed to be locked to the body, not the board?

jmamma, 2020-08-14:
the encoder nuts hold the front of the board in place. and the rectangular strip on back plate presses against the  the MIDI ports.

yatli, 2020-08-14:
Understood.
Placed the "tall" order + 8 encoders. 400 RMB. :D

jmamma, 2020-08-14:
Any idea what quality you printed at?

The encoders knobs might not fit the shaft, depending on the tolerances of the print.
I've had issues here ^

yatli, 2020-08-14:
I guess.. just the normal stuff. 0.1mm tolerance

yatli, 2020-08-14:
Oh and, they offer to embed 4 copper nuts in the body and I happily accepted :p

jmamma, 2020-08-14:
See how you go.

400 RMB sounds like a bargain.

jmamma, 2020-08-14:
Oh and, they offer to embed 4 copper nuts in the body and I happily accepted :p

For the screws?

yatli, 2020-08-14:
Yeah. The cylinders seems to be strong enough to hold them.

jmamma, 2020-08-14:
ha! One of my early designs tried this... The slots I made for the Nuts always ended up being thinner towards the corners, meaning I couldn't align the nuts with the holes correctly.

I gave up on this, and went for Self Tap screws. Which work surprisingly well.

yatli, 2020-08-14:
https://github.com/jmamma/MegaCommand_Design/commit/1339fe99583b68638f9dfa7dfdb793e1ff2d5c07

Emmm... I sent the old lid to them

jmamma, 2020-08-14:
No problem. The fit is dependent on your build. So it might be fine. If not you can just rotate the lid to not use the rise. Or if you still need some stability, you can file down the rise with sand paper.

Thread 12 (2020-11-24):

MCL / button and encoder test fail

zerkalo06, 2020-11-24:
Hello Justin and Yatao,

I create this issue after having a conversation with Justin on the elektronaut forum.

At first I had a problem with the sram test, but now after reflowing the ic everything is fine.
I then tried the button and encoder test and I got nothing from the serial monitor, so I checked the SN74LS165AN chips and I got those results (those are in volt of course, even tho I didn't specify it) :

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

I maybe have to check again and de-solder again the male headers as I don't get the same results from those now, 0v all across apart for 47 and +5. Maybe it's just due to the amount of solder, my voltmeter is not that great. Isn't it strange the sram test is still working ?

Here are the pics of my pcb (I replaced one 0,1uf capacitor missing by another ceramic one I had left) :

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

Thanks for your help, and great great work you doing here !

zerkalo06, 2020-11-24:
a better quality for my results doc :

[megacommand_1_0_2a12_top_bottom.pdf](https://github.com/jmamma/MegaCommand_Design/files/5590940/megacommand_1_0_2a12_top_bottom.pdf)

jmamma, 2020-11-24:
Better check the basics first.

After compiling MegaCommand Button & Encoder Test Firmware:

Sketch uses 2052 bytes (0%) of program storage space. Maximum is 253952 bytes.
Global variables use 190 bytes (2%) of dynamic memory, leaving 8002 bytes for local variables. Maximum is 8192 bytes.

Serial Monitor should be set to 9600 BAUD.

zerkalo06, 2020-11-25:
I checked. Everything is has intended.

jmamma, 2020-11-25:
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

Circuit diagram for reference

jmamma, 2020-11-25:
Background:

The two shift registers are cascaded together to form a 16bit register.
Each bit is representative of the state of switch (encoder button or button). The 16 signals from each of the switches INS[0-15] are connected in parallel to the inputs across both shift registers.

The data is streamed serially to the arduino via PL0.

Troubleshooting:

1) Can you verify the orientation of R1 and R2. The circular mark on the resistor(s) should be inline with the pin closest to the bottom of the board. The text should be visible from the right side of the board.

zerkalo06, 2020-11-26:
Thanks for the background infos !

If I understand you well R1 and R2 seems to be fine (english is not my first language, I might make mistakes).

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

jmamma, 2020-11-26:
yes they look okay.

jmamma, 2020-11-26:
Next step is to verify the continuity of the traces between IC3 and the Arduino.
(Use your multimeter to measure resistance. make sure the traces read close to 0 ohms.)

Please check:
PL0, PL1, PL2

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

Please measure from the solder points on the MegaCommand, and on the arduino itself.

zerkalo06, 2020-11-26:
R1 and R2 pins are measuring approx. 0 ohms , so that's good.

I got PL0 = 0v     PL1 = 4,80v     PL2 = 3,92v

Orientation is good for IC3, and measures seems to match with INS (0v all across, apart for SH/LD (4,82v) and CLK (3,90v))

Also from CLK to PL2 = 0,86v

jmamma, 2020-11-26:
```I got PL0 = 0v PL1 = 4,80v PL2 = 3,92v```

Voltages won't be much use here. You need to check the continuity of the traces on the PCB to check for damage. We need to see that there is a clear connection between IC3 and the Arduino.

(Use your multimeter to measure resistance. make sure the traces read close to 0 ohms.)

Please check:
PL0, PL1, PL2

zerkalo06, 2020-11-28:
Sorry I didn't understand the first time.

So

PL1 = 0 / PL1 = 0 / PL2 = 0

But there is problems of connection from IC3 to the arduino. None of them are working (results = 1).
There is a white kind of dot on the circuit near IC3, do you think it's flux residue ? I may have to clean it, maybe it's what causing the connection problem.

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

yatli, 2020-11-28:
What do you mean by `results = 1`?

yatli, 2020-11-28:
Also, I recommend using the continuity mode (the "beep mode") if your multimeter has one.
Put the two probes on the two target pins and it will beep if the two pins are connected by a path.
The signal path is a thing between two locations in a circuit, so that's why I don't understand your `result=1` thing -- `result=1` against which pin?

Currently you should measure that the correct pairs of locations are connected together:
`PL1 <-> IC3 SH/LD`:
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

`PL1 <-> IC2 SH/LD`:
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

`PL0 <-> IC3 QH`:
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

`PL2 <-> IC2 CLK`:
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

`PL2 <-> IC3 CLK`:
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

If all of these are connected well, you'll at least get something out of the serial console.

zerkalo06, 2020-11-29:
1 means its disconnected, and 0 that the path is connected, on ohm mode as my multimeter don't have continuity mode. I hope I use it properly. Only did few electronic pedals before this project, working with sound for troubleshooting, so I'm not used to it. Thanks for taking the time, and being patient : )

So

PL1 <-> IC3 = 0
PL1 <-> IC2 = 0
PL0 <-> IC3 = 0
PL2 <-> IC2 = 0
PL2 <-> IC3 = 0

IC2 SER <-> arduino GND = 0
IC2 A <-> INS 0 = 1
IC2 B <-> INS 1 = 1
IC2 C <-> INS 2 = 1
IC2 D <-> INS 3 = 1
IC2 E <-> INS 4 = 1
IC2 F <-> INS 5 = 1
IC2 G <-> INS 6 = 1
IC2 H <-> INS 7 = 1
IC2 INH <-> C1 = 0,01

IC2 QH <-> IC3 SER = 0

IC3 SER <-> arduino GND = 0
IC3 A <-> INS 8 = 1
IC3 B <-> INS 9 = 1
IC3 C <-> INS 10 = 1
IC3 D <-> INS 11 = 1
IC3 E <-> INS 12 = 1
IC3 F <-> INS 13 = 1
IC3 G <-> INS 14 = 1
IC3 H <-> INS 15 = 1
IC3 INH <-> C2 = 0,01

jmamma, 2020-11-29:
```
PL1 <-> IC3 = 0
PL1 <-> IC2 = 0
PL0 <-> IC3 = 0
PL2 <-> IC2 = 0
PL2 <-> IC3 = 0
```

Did you measure these from the solder points on the Arduino Mega?

jmamma, 2020-11-29:
[ ] Verify IC orientation.
[ ] Verify Trace continuity on board.
[ ] Verify Arduino Header continuity.
[ ] Voltage check.

--

If the above criteria are met, then by process of elimination that suggest either

[ ] short circuit somewhere.
[ ] faulty IC3

yatli, 2020-11-29:
IC2/IC3 orientation looking good:

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

zerkalo06, 2020-11-29:
Yes, I measured from the solder point of the pcb and the arduino.

yatli, 2020-11-29:
```
IC2 SER <-> arduino GND = 0
IC3 SER <-> arduino GND = 0
```

IC2 out and IC3 serial input shorted to ground.

zerkalo06, 2020-11-29:
Sorry, that's just a typo, that's what I meant (I verified, it's still good)

yatli, 2020-11-29:
So, `IC3 SER <-> arduino GND = 1`, correct?

zerkalo06, 2020-11-29:
Yes, that's correct

yatli, 2020-11-29:
```
IC2 A <-> INS 0 = 1
IC2 B <-> INS 1 = 1
IC2 C <-> INS 2 = 1
IC2 D <-> INS 3 = 1
IC2 E <-> INS 4 = 1
IC2 F <-> INS 5 = 1
IC2 G <-> INS 6 = 1
IC2 H <-> INS 7 = 1

IC3 A <-> INS 8 = 1
IC3 B <-> INS 9 = 1
IC3 C <-> INS 10 = 1
IC3 D <-> INS 11 = 1
IC3 E <-> INS 12 = 1
IC3 F <-> INS 13 = 1
IC3 G <-> INS 14 = 1
IC3 H <-> INS 15 = 1
```

These are suspicious. Should be all 0.

zerkalo06, 2020-11-29:
When we're talking about INS1 INS2 etc, we are talking about those ones right ?

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

yatli, 2020-11-29:
No, these are arduino pin numbers, which we're not using. Instead we are using the RAW ATMega2560 pin numbers, as shown by @jmamma.

INS pins for the encoders:

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

yatli, 2020-11-29:
INS pins for the buttons:

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

zerkalo06, 2020-11-29:
Okay my bad. Here we go :

IC2 A <-> INS 0 = 0
IC2 B <-> INS 1 = 0
IC2 C <-> INS 2 = 0
IC2 D <-> INS 3 = 0
IC2 E <-> INS 4 = 0
IC2 F <-> INS 5 = 0
IC2 G <-> INS 6 = 0
IC2 H <-> INS 7 = 0
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
zerkalo06, 2020-12-08:
Hi ! I receive a new multimeter and did the measures again, oorah.

SRAM test still working.

**For R1 <-> GND  (without usb connected) :**

All pins = 0v

or

Pin 1 = 5 kΩ
Pin2, 3, 5, 6, 7, 8, 9 = 15 kΩ
Pin4 = 0,2Ω

** R1 <-> GND (with usb connected) :**

1, 2, 3, 5, 6, 8, 9 = 3,6v
4, 7 = 0v

**R2 <-> GND  (without usb connected) :**

All pins = 0v

or

Pin 1  = 5 kΩ
Pin 2, 3, 4, 5, 6, 7, 8, 9 = 15 kΩ

** R2 <-> GND (with usb connected) :**

1, 2, 3, 5, 6, 7, 8, 9 = 3,6v
4 = 0v

Regarding the measures for the encoders (voltage without usb connected, GND <-> INS) I got 0v everywhere.

Also :

IC2 H <-> GND = 3,6v to 0v(with button pushed)

zerkalo06, 2020-12-13:
I redid the soldering on R1 and R2 and the encoders. Nothing new with the resistors.

I then checked the continuity of the encoders and INS1, INS2, INS3, INS4, INS5, INS8, INS9, INS10, INS11, INS12, INS13, INS14, INS15 don't seem to be connected.

I'll tried to re-solder them but I'm a bit worried that I'll damage the circuit by doing it a forth time.

jmamma, 2020-12-13:
```I then checked the continuity of the encoders and INS1, INS2, INS3, INS4, INS5, INS8, INS9, INS10, INS11, INS12, INS13, INS14, INS15 don't seem to be connected.
```

Highly unlikely. How did you measure this ?

zerkalo06, 2020-12-15:
By attaching black probe to gnd and red probe to each encoders INS pins on the continuity mode, and with the arduino connected. It beeped for only two of them. I had four of them before I re-soldered their pins ...

jmamma, 2020-12-15:
Black probe to GND, and red to INS pin.

Did you push the corresponding button to complete the circuit when testing the continuity ?

jmamma, 2020-12-15:
To recap.

```
Did you measure the voltage on R1, and R2 resistor arrays.

On each array, the pin closest to the bottom of the board should read 5V with respect to GND.
```

Are you still reading 0V on the resistor arrays ?

Which pin on the mega command circuit board are you connecting the black probe to measure GND?

zerkalo06, 2020-12-16:
Okay thanks, my bad I didn't push the encoder while checking the continuity. They all good.

For R1 and R2 I get only 3,7v on all pins when moving the encoders.

I get GND from the point indicated above by yatlin, near button 2 and marked by a GND sign on the pcb.

jmamma, 2020-12-16:
Okay good to know that.

On each array, the pin closest to the bottom of the board should read 5V with respect to GND.

This is the supply voltage to the resistor array. Can you verify that it is constant. It should read 5V without rotating encoder or pushing button.

zerkalo06, 2020-12-16:
The supply voltage is constant on the two resistor array but only reading 3,7v or 3,9v depending if the board is powered by a computer or a electrical outlet.

jmamma, 2020-12-16:
Understood.

Can you measure the 5V voltage being supplied by the Arduino Mega.

When viewed from above, the double header has GND, and 5V labelling

zerkalo06, 2020-12-16:
I get 4,8v from both double header.

jmamma, 2020-12-16:
Okay. There's another 5V supply rail that comes off the right most Arduino header in the middle of the board.

I suspect this rail is being dragged down by a failing component. I have a strategy for narrowing it down.

Just putting together a diagram.

jmamma, 2020-12-16:
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

jmamma, 2020-12-16:
All the elements are connected in parallel, so unfortunately each node along that path will measure the same voltage. You measured it at approx 3.7 V.

jmamma, 2020-12-16:
What we know:

SRAM is working. It can run on a supply voltage as low as 2.7V
The Octal latch is working. It must be if SRAM is working. It can run on a low 2V supply voltage.

The shift registers require 4.7V to run. Either one of these could be faulty.

Octo-couplers require 4.5V. Either of these could be faulty.

R1 or R2 should be okay, given your voltage + button test above.

jmamma, 2020-12-16:
So the only option here is to start replacing components connected to the 5V rail. Unfortunately because you soldered up the MIDI circuits, you have two extra ICs that could be to blame.

1) Shift registers.
2) Octal Couplers.
3) Capacitors that are on the 5V rail. <-- easy starting point.

jmamma, 2020-12-16:
So the procedure is:

a) Remove component.
b) Test the 5V rail.
c) If 5V rail voltage is measuring 5V you know you've found the problem component.

zerkalo06, 2021-09-16:
Hey Justin and Yatao ! Just to let you know I've finally manage to finish my mcl. Thanks so much for your help ! Silly mistake I just forgot to put the middle male headers ... So anybody passing by just take time to verify everything, and don't hesitate to let it sit for a time and come back to it with a more clear vision. Thanks again for all the work you're put into the mcl and md projects !

Closed 2021-09-16.

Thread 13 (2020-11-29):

MEC Switch + LED?

yatli, 2020-11-29:
Didn't know that the switch is designed to host an LED in there:

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

So in theory we should be able to get 4xLEDs on the board but maintain compatibility with the current one.

yatli, 2020-11-29:
The 1E hat is LED compatible:

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

jmamma, 2020-12-10:
Good find. I never even thought of this.

You still need to route from the arduino to the LEDs, obviously.

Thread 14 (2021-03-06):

Shift1 not working

defalutz, 2021-03-06:
Justin advised me to make an issue here so here goes..

I´ve built about 50+ MCL´s, many thanks to the group buy i organized a while ago, word spread - suddenly i had orders to build to a whole bunch of longing MD users - which was fun and it paid for my own unit plus i like to build and solder stuff, and since this being TH it was a bit easier than i normally build. So most of the units worked great. I think i have had until now maybe 3 with bugs needing to be fixed. Simple stuff, just me being sloppy doing bad solder joints, and one being a memcard not working.

BUT everything has an end! And suddenly i have **two** issues being tricky for me to fix without help, this is one of them.

The issue is with the lower left pushbutton (Shift1); the one that opens the menu. It´s doesn´t do anything at all, no reaction.

To fix it, I tried these things:

- re-soldering the ICs, the button itself and in general cheking for bad soldering, which i didn´t find
- ran the SRAM test without any trouble
- tried swapping between three different arduino boards, that is not the issue, when i out any of them in my own unit, the one i have used the longest, everything works with no trouble
- ran the button and encoder test = **FAIL** on just the button i have problem with, obviously

What have i done that MIGHT affect the function of the button?
The only thing that i MIGHT have changed is that instead of the 220 ohm resistors i put 221 ohm ones instead, possibly. I was out of 220´s and figured it shouldn´t matter, not with so little difference.. :)
Also, i have another 9v on/off switch than the EG1218 thats recommended but it works fine in the other machiens that use it, and i have the problem both when running on 9v power and usb so.. shouldn´t be that. Besides it be a little cramped for space and the switch casing are about 1mm or less from three of the SRAM legs i can´t see any problem with it.

I attach some pics of the front and back. Any ideas what to do; replace the button? Or some testpoint that i should check? I´m not super-good at Eagle, i can manage but far from an expert.

If you could give me some pointers i would be very grateful. I´m about to remove the button and test with another one but atm i don´t have one, but waiting for delivery from mouser next week, early to middle

Front:
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

Back:
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

Thanks in advance! //Marcus

jmamma, 2021-03-07:
Hey Marcus.

You need to get ahold of a multimeter and check the traces connected to the push button.

It's most likely a bad trace, bad solder joint, or short circuit on one of those traces.

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

jmamma, 2021-03-07:
You can check traces by setting the multimeter to measure resistance. And verify that there is continuity from point to point. Continuity means the trace should measure close to 0 ohms.

defalutz, 2021-03-07:
I have one, will check as suggested and teturn with results. Thanks!

jmamma, 2021-03-07:
So it's BUTTON 2.

The trace to check is INS13.

defalutz, 2021-03-07:
> You can check traces by setting the multimeter to measure resistance. And verify that there is continuity from point to point. Continuity means the trace should measure close to 0 ohms.

I have measured continuity before, my meter beeps when i have it.
The thing about checking traces is good, very useful, thanks!

jmamma, 2021-03-07:
It might not be immediately clear from the circuit diagram, but INS13 is also connected to IC3 (shift register)

Also check the traces on C16.

jmamma, 2021-03-07:
It might not be immediately clear from the circuit diagram, but INS13 is also connected to IC3 (shift register)

Also check the traces on C16.

jmamma, 2021-03-07:
edit: just re-uploaded the traces image because the previous one had some unrelated markings.

defalutz, 2021-03-07:
> edit: just re-uploaded the traces image because the previous one had some unrelated markings.

Great, thanks for the assist, i will test as soon as fatherhood allows. ;)

Off topic
On another note; cant the most skilled with the MCL record a few short vidz that Showcase cool stuff the MCL can do and the Md alone cant? Just to build interest. Food for thought at least, i would IF i had the skills but sadly i have spent My time building. ;)

defalutz, 2021-03-19:
Ok, took a while, but i finally tested with a multimeter. GND for Button 2 was ok. INS13 though did not connect with the corresponding leg joint on IC3.
I used a fully working finished board to compare with just to be sure when testing.
I replaced C24 but problem persisted. When i tried with the working comparison board i got a beep from the button´s INS13 joints all the way to IC3.

On the error board, when i test between the C24 and IC3 it works, i get a beep, but no beep between button 2 and C24.

I have resoldered the button to make sure but didn´t help. A faulty button might be the issue?
Anything else that i can test?
I am waiting for a mouser shipment, as soon as it arrives i can replace the button2 with a new one, i just hope that this is the issue, but it sounds like it, or what do you think?

Attach a picture with encircled areas of trouble and such.
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

jmamma, 2021-03-19:
``` INS13 though did not connect with the corresponding leg joint on IC3.```

The INS13 trace is probably no good.  Try soldering a wire from the shift register directly to the button.

You can't always rely that the PCBs come from the manufacturer in perfect shape.

defalutz, 2021-03-19:
Of course, that might be the issue! I´ve had lots of good boards and no trouble with them thusfar, but it was bound to happen someday. I will try your solution!

Just a follow-up question though.  I drew a white line where i think i´m supposed to do the bypass; but this also bypasses C24 and in the end of INS13 it splits to also connect to the end of R2, the resistor network/matrix or whatever it´s called. What about that? I don´t really know what result that would give if the signal don´t go there also. What do you think?

I could also try do do a small bypass instead, if the trace is just broken from the button2 to the C24 i can solder a small wire between those two instead of a long one and keep the rest of the signal structure intact?

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

defalutz, 2021-03-19:
Thanks for the support, i´m not as good at troubleshooting as i wish i would be so - thanks for being available! :)

I´m not worried about damage to the resistor array, just wondering about this;

* if i choose option #1, with the long cable, i will need to emulate the board design by adding a capacitor like C24 first, then do what i assume is a split of the signal (in the large white circle) that divides the signal so that one goes to the shift register IC3, and the other to the last joint on the R2 array - is this correct?

defalutz, 2021-03-19:
Ah, solved it! Alll i needed to do was to solder a small wire between button 2 and C24 and PRESTO! it worked. :)
Many thanks for your help justin, you and Yateo are the BEST! :)

Closed 2021-03-19.

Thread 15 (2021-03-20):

Too much peering for comfort!

defalutz, 2021-03-20:
Hi,

i have a unit that does an unusual large amount of peering. It still works but especially when i from the grid enter the settings menu, it shows up at every step and takes some additional time that feels too long.
Of all the units i have built before, this is the first i notice this excessive peering.
It behaves fine besides that afaik.
I have 3.10d installed, as long as X.04 on the MD.
I have run the ram test without issue.
What do you recommend checking?
In the MCL thread at elektronauts Justin recommended taking a look at midi communication on port 1. Anything else that i should be looking for?

Thanks in advance!

defalutz, 2021-03-20:
Ok, done some testing in eagle, and this is the result.

I´ve examined N$14 och N$15, the only ones that have a signal going elsewhere from midi jack 1, U$10

N$14 connects proper to D1 = **OK**,  and then to OK1 (one of the optocouplers 6N137) and leg number 3 there = **OK**

N$15 only goes to R5 and it connects **OK**.

jmamma, 2021-03-21:
sram test?

jmamma, 2021-03-21:
There should be MIDI IN and MIDI OUT test firmwares, you'll need to hookup a MIDI keyboard from memory.

defalutz, 2021-03-21:
> There should be MIDI IN and MIDI OUT test firmwares, you'll need to hookup a MIDI keyboard from memory.

Aha! That's good, i hope it will help.
The problem is so small i almost skipped posting it here, but i Will see if i can shoot a video and show to you just to clear it Up a bit.

What do you mean to hookup a KB "from memory"?

Best,
Marcus

yatli, 2021-03-21:
guess "from memory" is short for "iirc" :D

yatli, 2021-03-21:
what I did back then is to loopback the midi ports and verify the data.

defalutz, 2021-03-22:
Ok, i checked the midi in with a keyboard and out with midi monitor in bitwig; seems like a get a proper response, or what do you think? I get no breaks, nothing strange happening and the values seem correct. Besides that midi monitor in bitgi doesn´t say note "off" it gives two "on " on the same note.. but it seems to be normal for it. Attached some screenshots to verify!

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

jmamma, 2021-03-22:
note_on when velocity = 0, is note off.  so the two note_on messages are okay.

jmamma, 2021-03-22:
Can you try adjusting turbo settings on the faulty port.
Start at 2x, and work your way up.

See if peering is okay at lower speed?

Also, have you tried another arduino ?

defalutz, 2021-03-22:
I will check that. But i don´t know which port is faulty, but i will try with in 1 first as you say.

Yes, i have tried with at least three different arduino boards so i´m pretty sure it works. Also even tried with a clone board. Same same.
But the things i can test you mentioned is a good idea, i´ll be back with results. Thank you. :)

jmamma, 2021-03-22:
What image is being displayed on the Peering screen. Is it the Machinedrum?

If not, in MCL global settings menu. check Settings -> MIDI -> Device 2

Set this to GENER for General MIDI.

defalutz, 2021-03-22:
Eh... do you mean MCL can show a different image depending on the device connected when it says "peering"? Not sure actually but i will check now!

defalutz, 2021-03-22:
Well, i checked what you suggested; i had elektron as device two, but since i use port two in to get clock from my DAW it makes more sense to set it to generic.
I don´t know what´s changed but suddenly i don´t get the peering screen almost at all anymore. Tried changing turbo settings but that didn´t change anything so now i leave it at 8x.
But it makes more sense to lease the p2 at generic.
Dont know why but suddenly i have no errors anymore so i guess the unit it ok?
All i have dome besides error searching and what you suggested was re-upload the firmware again to it, but nothing new.

But anyway, i think i will send it to the customer and be done with it since it now shows no bugs at all.

And if he has bugs i have the thread with suggestions.
Thanks for the assistance, at least i have learned something. :)

jmamma, 2021-03-22:
I noticed setting Device 2: to Elekt will cause the MC to try and peer even if there is no MIDI activity.
That might be what you were seeing

defalutz, 2021-03-22:
Yes, that might be the case. Though i´m pretty sure i have done it before without trouble but i can be wrong. But it seems to work now so all good. :)

Closed 2021-03-22.

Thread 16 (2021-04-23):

Leftmost encoder SW1 not working, INS0 not connecting with res.matrix R2

defalutz, 2021-04-23:
I had trouble with odd behaviour from the module, after looking over it a few times for the most obvious faults i found the problem.

The inner (R2) of the two resistor matrices was oriented the wrong way around, so it had the text pointing into center of the board instead of outwards as the outer one was/is.

I had a little trouble removing it so i worried (not without cause, it seems) that it would come with a large bill in the end.

Result:

The first encoder (SW1 in eagle), the leftmost, does not work at all. I cannot more the cursor or do anything, change values and so on.

After testing the connectors, one after another:

ins8 har conn to end destination = OK
ins1 as above = OK
ins0 connects to the next to last point, which is on IC2 but not after that!

The next and last connection for INS0 is with the the third point on R2. This is not happening.

I have tried with the multimeter on the bottom side and on the top side between the yellow "sausage" of the matrix itself - both tries without success.

I must have f*cked something up when desoldering it or it didnt work from the start, who knows?

I am no master at desoldering so it walways gives me the shivers when i have multiple points i have to desolder to remove something. It´s 50/50 to succeed.
I forgot that i have a hot air soldering/desoldering station i could have used instead but now it´s probably too late. Or that do you think, should i try again ?

I´m not sure it will work even if i do it better next time because there might be some broken trace or something that is the cause. Of maybe one of the other solder joints to the matrix is fudged, who knows?

I could try it of course and will do if i cant figure out something else.

But i wonder uf there is anything else i can do instead of drastic things. Or any other drastic things i can try? How can i get INS0 to connect even if the solder joint is gone? Can i solder a small cable or jumper from the topside closest to the "sausage" to somewhere else? It´s not clear to me where it goes next or how the matrix even works?

Any ideas? Thanks!

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

jmamma, 2021-04-24:
The board can be easily damaged during a desolder attempt.

If the trace is damaged you'll have to repair it using a jump wire like before.

If the pad is damaged, you'll have to solder a wire directly to the pin on the resistor.
Another solution would be to solder a 10K resistor between INS0 and +5V . This would bypass the resistor array.

defalutz, 2021-04-24:
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

I can do both of the two later solutions without problem, but it doesn´t affect anything else by doing that?
You shouldn´t have recommended it if it had of course, but.. just asking..

Ok, i will try to do the jumper first; just to make sure, you mean i should put a jumper like this below? Looks crappy i know but at least the angle makes it possible to do.

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

defalutz, 2021-04-24:
Alright, i´ve read up a bit on the resistor NETWORKS (not matrices)... doh.. And the solution suggested worked just fine, thanks. I soldered a thin cable and now the unit works great - plus i have learned a lot. And next time i will use other techniques when having to de-solder components like this.
Thanks. Issue closed. :)

Closed 2021-04-24.

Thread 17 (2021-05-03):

PROG NOT COMPATIBLE

albadort76, 2021-05-03:
Hi,
 All was fine with my MCL 3.10d until i the SD card has been broken in use. Can't repair it with disk utility.
Since i have a new SD card 16go FAT 32 formated, i try to create empty project just to check if it's working (without the MD connected to). Some of the project created are working some others are "NOT COMPATIBLE" project. For this kind of files, during the creation process, MCL shut down and restart before the end of the process.
I think i have a problem around the SD card somewhere, before this all was working good...

albadort76, 2021-05-03:
After several tests it seems to work again! Connection issue?

jmamma, 2021-05-05:
Sorry. I thought I replied. The issue could be a connection issue with the SDCard holder. Maybe a bad solder joint?

Depending on your soldering skills, and soldering iron, it is possible to reflow the SDCard holder pads with the screen still in place.

albadort76, 2021-05-05:
No problem!
 Hopefully got a good soldering iron with a very fine head so that's exactly what i have done everything's seems to be fine since with the new SD card.
  Hard to find them under 32go now, maybe some day all this space will be useful (WAV!! :)) ? I'm working on a new track i let you know. Cheers

jmamma, 2021-06-17:
@albadort76 have you had any additional problems with the SD card since your last post?

albadort76, 2021-06-17:
No more problem with the new sd card after reflewing solder joints.

jmamma, 2021-06-17:
Good to hear. I gave the SD Card code a once over. Found some scenarios where reads could be unreliable. So that will be improved in next version.

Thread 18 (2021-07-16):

MIDI send/receive firmware test fail

jabarbanel, 2021-07-16:
Hi Justin-

I have moved this issue over from the Elektronauts forum. I posted there last week about having issues with the MIDI ins and outs of my MegaCommand build.

Summary - I've been building my MegaCommand as per the instructions on GitHub. Passed the SRAM and button/encoder tests and have now hit a wall at the MIDI out/in firmware tests.

My setup: I have a MOTU MIDI Express XT connected to my PC and Ableton. I’m using the front panel MIDI ports (channel 8) to send/receive. With my Machinedrum connected, I can play sounds from the machinedrum with my keyboard, and when I play a pattern on the machinedrum I see MIDI note info lighting up on the MIDI interface (as well as in Ableton). So I confirmed that the MIDI setup is working as it should.

Here is the latest update on what I have done as far as troubleshooting: I am only working on the MIDI out circuit since it is so simple - but I did confirm the optoisolators are installed correctly for the input circuits.

1. Confirmed the Arduino is functioning properly. I was able to recreate the MIDI out circuit on a breadboard to confirm my Arduino is working:
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
With this setup I ran the MegaCommand MIDI-out test firmware and confirmed note data being received by my MIDI interface.
(side note - I was working with an older cheap arduino clone that had the rx1/tx1 pins either mislabeled or miswired, so I bought another clone and confirmed the pins are correct and functional)

2. Checked continuity between all the points of the MIDI send/receive circuitry on the pcb between from the arduino headers all the way to the MIDI connectors - everything looks good.

3. Cleaned the PCB with 99% Isopropyl Alcohol

4.  Checked another PCB from my order (I had the minimum of 5 made) by connecting only the MIDI out connections and resistors for TX1 output (see picture) - and WAS able to produce MIDI out notes that I confirmed on my interface:
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

5. Visual inspection of solder joints (looks OK to my untrained eyes)

6. Used a multimeter to confirm the resistors are 220Ohm - check

I'm really confused about this! I really would appreciate any insight / guidance on how to proceed at this point. Also here are pics of the build so far for reference.

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

Thanks for your time Justin, I really appreciate it.
-Jonathan

jmamma, 2021-07-17:
Jonathan your MIDI jacks are installed on the wrong side of the PCB!!

jmamma, 2021-07-17:
Please see the reference photography.

https://github.com/jmamma/MegaCommand_Design/tree/master/1_0_2/photos

jabarbanel, 2021-07-17:
omg. I wish there was a word for feeling simultaneously elated and mortified at the same time. Elated to have the solution be so simple and obvious. Mortified that I made such a bonehead rookie mistake.

Anyway thanks for the response! I have some fun desoldering work ahead - just ordered a fresh roll of desoldering braid because my solder sucker isn't removing enough to remove these jacks.

I'll post a confirmation once I get these jacks installed properly just to have some closure.

Thanks again Justin. I'll just show myself out...
<html>
<body>
<!--StartFragment-->

:flushed:
--

<br class="Apple-interchange-newline"><!--EndFragment-->
</body>
</html>

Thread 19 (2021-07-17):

Trouble with sram test and unit not working

defalutz, 2021-07-17:
Hi,
i have a unit that has given me a lot of headache, Sold it to a guy who cotacted me since he had trouble. It was working perfect when unit was tested here, and then i sent it. He contacted me, long story short but said he had "sd card error" message.

I got it back, saw that the arduino board had just about got unstuck so i put it back in place properly, also put a distance between the ard board and the lid som it was locked into place. Unit worked fine afaik.

Ok, got the same email again, decided i will have a look again and will let him buy it back after a while. But when i get it i have "sd card error" when i boot it up.
Just in case i reinstall latest firmware (whch is one step later than before). Boot it, everything works. Shut it down. Boot it. "Sd card error."

Weird, right?

I try a tip i read somewhere, test the voltage and ground, and all the IC circuits have 4.98 or 4.99volt in the right places, and 3.3 volt where it should be.

Ok, so i decide to run the test firmwares. The SD card firmware runs without ANY problems. Also the screen flashes black/white
Buttons work great. Midi i decide not to bother with. But the i try the sram test firmware nd all i get is this:

"Megacommand SRAM test
2200"

.. and nore more.. And that´s all. Tried a lot of things, reflowed solder joints and so on and forth, even got so far as to order replacement SRAMs.
Managed to desolder the old pretty niceliy.. Result? the **S A M E!**

Now i test with other units i am building, one so far has been tested this way (it´s missing screen, 9v switch, knobs and stuff, leds and resistors for leds, but should work the the testst i want to run. Ir runs great on the ones i used before but get the same result for SRAM test, 2200 and then STOP.

What the heck am i doing wrong? Any ideas? I have never had any customer get this issue before and i have built a LOT of MCL´s for people...

defalutz, 2021-07-17:
Oh, forgot to mention; now the unit that i had the initial problem with dont display anything on the OLED, even if i install the new firmware via xloader, it´s just black. And it worked fine before, i havend done eny desolering of just this part. Thanks!

defalutz, 2021-07-28:
The issue is weird; i have a short on the resistor arrrays, on the third pair from the top, ics3 and ics7. The only pair that´s supposed to be connected is the lowest pair furthest away from the midi ports.

Also, both these two joints (ics3 / 7) also beeps when i connect to pot 1, 2 and 4 and the top leg "b".
Very weird!
All i can think iof is that the PCB is wrecked.
Anone with any ideas?
I would like to try to bypass in some way but not sure how. I have dessoldered the resistor networks and still have the same issue..

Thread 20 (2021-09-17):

Peering issue

sc0rdatura, 2021-09-17:
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

Hi :),

I’m just flagging up that my megacommand keeps getting stuck on peering when it’s connected to the MD mk2. This is despite all tests passing and the MD and MegaCommand both being updated to the latest firmwares. I’ve tried a few different MIDI cables but it’s the same still, and the ports all pass the MIDI tests.

Thanks for your help!

jmamma, 2021-09-17:
What type of solder did you use? Post a photo of the label ?

You have a lot of flux residue covering the pads of the MIDI ports.

sc0rdatura, 2021-09-17:
It’s 60/40 Sn/Pb 5C ersin flux. Don’t have the label on the solder anymore but I know that’s what it is.

jmamma, 2021-09-17:
Ersin 5C solder apparently uses a rosin flux, so it should be non-conductive.

https://rmscomponents.com.au/wp-content/uploads/2018/02/Multicore-Ersin-Fluxes.pdf

sc0rdatura, 2021-09-18:
I have inspected/reflowed the joints around the MIDI jacks but sadly the problem persists. The flux doesn’t seem to be the issue.

jmamma, 2021-09-18:
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

Can you reflow the joints highlighted in GREEN. This is the header linking the MIDI circuitry to the Arduino. Corrosion on the pins and or bad header on the Arduino could also be a source of intermittent connection issue.

Please clean your board of any left over solder blobs located in YELLOW and elsewhere on your board.

sc0rdatura, 2021-09-18:
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

I have inspected all the joints on the board, reflowed (especially those in green) and removed flux for good measure. Solder blobs have also been removed. The issues sadly still persists. The peering sequence follows a pattern, whereby as soon as the MIDI in of the MegaCommand is connected to the MD it says “peering”. The progress bar moves for 10 secs or so then freezes, and then briefly flashes to the grid mode for 0.5 seconds before returning to the peering screen.

jmamma, 2021-09-18:
What happens if you set Config -> MIDI -> TURBO 1: 1x

jmamma, 2021-09-18:
I've uploaded the MIDI circuitry for reference.

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

I suspect the pullup resistors R11 and R12 highlighted in yellow are of incorrect value. They look different to mine.
Can you check what part you used? They should be 1Kohm

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

sc0rdatura, 2021-09-18:
Have just tried, sadly no change still.

sc0rdatura, 2021-09-18:
Have tried both the 1x midi setting and confirmed the resistor values are at 1k by Color code and measurement. Still getting the same result.

jmamma, 2021-09-18:
You can check supply voltage to the 6n137s with a multimeter. Supply voltage should be 5V.

sc0rdatura, 2021-09-18:
Can confirm the couplers are getting the correct voltages.

jmamma, 2021-09-18:
Do you have another Arduino you could test with ?

sc0rdatura, 2021-09-18:
Sadly I don’t have a spare arduino mega, but is the arduino a possibility even if all of the build firmware tests pass?

jmamma, 2021-09-18:
yes. could be a bad connector or dodgy board.

The MIDI firmware test is only testing note data. not large streams of SYSEX which are exchanged during peering.

jmamma, 2021-09-18:
With the Arduino removed. You could use your multimeter to measure resistance between TXD1 and PIN5 of the MIDI OUT 1

It should read 220 ohms.

sc0rdatura, 2021-09-18:
Yup that all looks good as well. Just did some testing around the midi jacks/couplers with the multimeter and your schematic and everything seems in order.

jmamma, 2021-09-18:
Running out of potential candidates.

1) Can you measure GND on the 6n137s against GND on the double pin header. It should read 0V

2) Are you powering via USB or DC? you could try the other.

3) Do you have an Analog 4 or MNM ? If so, you could try connecting one of those on PORT2 and see if peering is working  on PORT2.

jmamma, 2021-09-19:
Probably should have checked the most obvious first.

You connected 2 MIDI cables between the MD and MCL ?

Peering requires both MIDI IN and MIDI OUT connection to the MD.

sc0rdatura, 2021-09-19:
I’ve been trying both with USB and DC, to see if it would make any difference, but alas not.

I don’t have either to test port 2 sadly.

Yes I’ve been connecting MIDI both in and out. The peering only starts showing when I plug in the out of MD to in of MCL.

frnktrpz, 2021-09-19:
Hope it's ok for me to comment here but if I were you I'd give the whole board another reflowing, still a bunch of dodgy looking joints imho. And after that give it a really thorough clean with isoprop and a toothbrush, clean it til it's spotless and then go over it with a can of compressed air, blow it under the ic's while holding the board sideways and into the headers with the board upside down.
I had some issues last year and everything was resolved after really properly cleaning the board.

defalutz, 2021-11-10:
Hey, i have Some peering issues, this One just won't start peeering what ever i do. I have reflowed as much as felt reaśonable at the moment. Cables are fine since i used Them yesterday to this purpose. I have cleaned the board reasonably thorough.

Heres a few pics, can you see anything out of the ordinarie?
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

jmamma, 2021-11-10:
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

The silk screen seems to be missing near some of the solder pads?

If solder bleeds from a pad to nearby exposed copper, it could result in a short.

defalutz, 2021-11-11:
Yes, i noticed that myself when i posted, i saw in eagle that two traces from the first midi port go to the right and i'll check if One of Them is Close to this exposed copper and if there is a connection where it should not be. Hopefullly it's a matter of cutting the trace!
Thx, Will let you know! :)

jmamma, 2021-11-11:
You shouldnt need to cut any traces, just make sure you dont have any shorts by solder sticking to copper where it shouldnt be.

defalutz, 2021-11-11:
Ok, got it. Unfortunately it didnt make a difference.
Back to experimenting. Peering, Short break, peering and so on. I'll check in some of the other ideas in the thread too.

defalutz, 2021-12-04:
Hey guys; i have actually found out some interesting things. On the main midi ports, peering just restarts all the time. On the secondary midi ports, if i set them to elektron and to receive midi, peering works. Though i havent found nything that differs from them right now. Any ideas? Thanks. Pics coming soon! Anything except the 6n137 i should check voltage on - or any ideas on how to compare the ports properly?

frnktrpz, 2021-12-05:
Don't mean to come off harsh here but I'd prioritize improving your soldering and keeping your boards clean before chasing down errors. From the pictures you posted there seem to be quite a few soldering points across the board that need reflowing/reworking. Maybe it's the lighting in the pictures but it looks like there might be a couple of cold joints, insufficient wetting and with double sided boards you generally want to be aiming to get a nice small concave mound on the component side as well as the solder side. (https://www.manualslib.com/manual/2085266/Thonk-Eurorack-Diy-Kit.html?page=2)
Also there seems to be a rather large amount of debris (dust/specks of solder?) on the board and components. And what's up with all the bits of missing soldering mask?

defalutz, 2021-12-05:
No, dont worry. I appreciate the input. And it´s true. The issues you describe is because of
1. stress, a lot to do and too little time, so unfortunately in some cases i might have been sloppy soldering
2. my usual solder ran out, i had to use one with different characteristics, and at the same time i started using new tips for my soldering iron and together they behaved not as i am used to - it got a lot harder to get the joints to look the proper way so it´s entirely possible it might be a few cold joints and so on and so forth.
3. I got a batch of low quality PCBs  at the same time as the above things, and where i had NO problems before, suddenly with this batch i started having isues all over.
I usually clean up the build so unfortunately you got pics taken from before the clean-up.

The solder mask was very sensitive (again, this high level of sensitivity i´m not used to) so it came off during certain manouvres or if i had to desolder a component and replace if with another.

Again, thanks for the hints. I realize i have to find a better combination of solder and tip for the iron, a pair that work better together. Also, i need to clean up the board before and after better, to make the solder stick better for example..

I´ve made a sh*tload of working MCL units before so this has baffled me a bit, but i´ll cope with it. At the moment i´m quite annoyed with the boards used for the three units i´ve had trouble with, so i will send them into a black hole after removing all useful components. Then they will end up on different PCB´s that i´ve had zero trouble with so far..

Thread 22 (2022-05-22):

SRAM Addressing issue?

possan, 2022-05-22:
Hello, i was handed a "broken" MegaCommand device and just started to do some basic reflowing of the solder joints.

After running a few of the testing firmwares successfully, it finally failed on the SRAM one, i modified it a bit to print out what it reads from which address and that's when i saw an interesting pattern, it seems like the two lowest address bits are high which means it reads a slightly higher address than expected, every fourth read is correct.

```
Address 22F7 (10001011110111)  correct F7 (11110111)
Address 22F8 (10001011111000)  read FB (11111011)  expected F8 (11111000)
Address 22F9 (10001011111001)  read FB (11111011)  expected F9 (11111001)
Address 22FA (10001011111010)  read FB (11111011)  expected FA (11111010)
Address 22FB (10001011111011)  correct FB (11111011)
Address 22FC (10001011111100)  read FF (11111111)  expected FC (11111100)
Address 22FD (10001011111101)  read FF (11111111)  expected FD (11111101)
Address 22FE (10001011111110)  read FF (11111111)  expected FE (11111110)
Address 22FF (10001011111111)  correct FF (11111111)
Address 2300 (10001100000000)  read 3 (11)  expected 0 (0)
Address 2301 (10001100000001)  read 3 (11)  expected 1 (1)
Address 2302 (10001100000010)  read 3 (11)  expected 2 (10)
Address 2303 (10001100000011)  correct 3 (11)
Address 2304 (10001100000100)  read 7 (111)  expected 4 (100)
Address 2305 (10001100000101)  read 7 (111)  expected 5 (101)
Address 2306 (10001100000110)  read 7 (111)  expected 6 (110)
Address 2307 (10001100000111)  correct 7 (111)
```

I checked the traces between the Arduino data pins and the sram and latch, and they seem correct and no crosstalk.

I'm suspecting that the latch is broken, but it seems weird that only a few bits of the latch is broken, and i haven't been able to run it through a scope yet so i'm not sure if they're actually high or low.

I'm just curious if anyone have seen something like this before?

jmamma, 2022-05-23:
It sounds like you're pretty close to finding the problem.

This is the reference diagram for the SRAM from the Atmega 2560 datasheet.

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

With the aid of the Latch, AD7:0 is providing both high Address lines and Data, if the problem was on the AVR side you would expect to see stuck bits in the data as well.

Are all the reads ending in 0b11 ??

possan, 2022-05-24:
Not sure, it seems like it, i guess i could try that by just writing the two lowest bits as zero and see what it returns, i'll do some more digging in a few days..

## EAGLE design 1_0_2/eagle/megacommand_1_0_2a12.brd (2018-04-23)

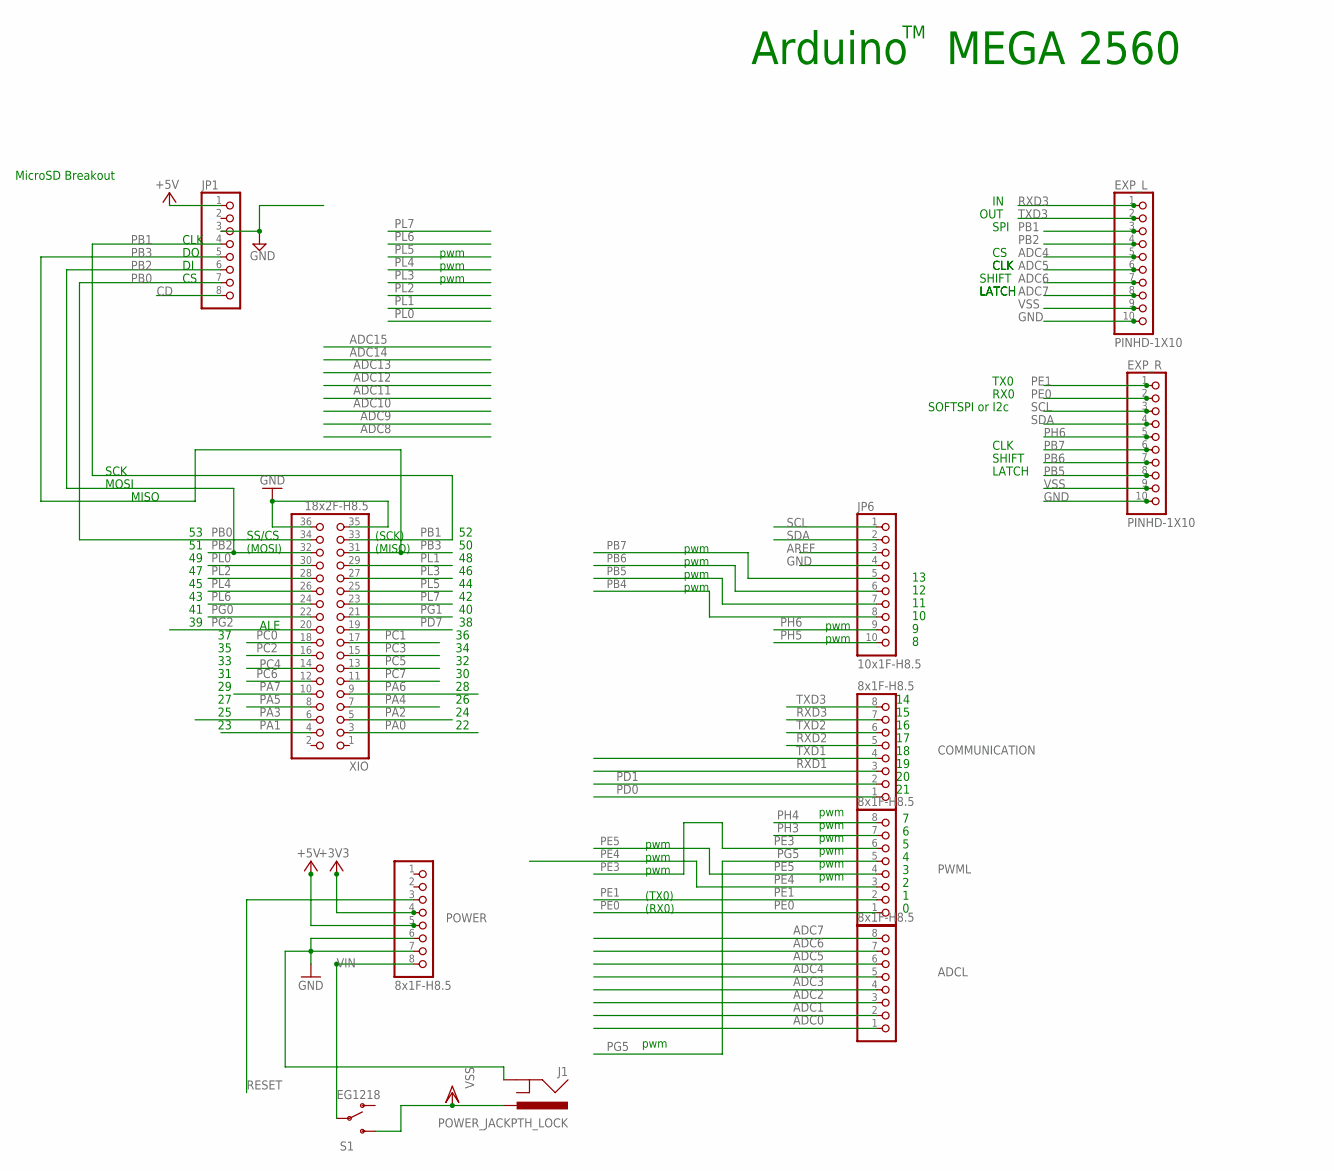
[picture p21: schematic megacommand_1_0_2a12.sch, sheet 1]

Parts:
ADCL: 8x1F-H8.5; 1X08
COMMUNICATION: 8x1F-H8.5; 1X08
EXP_L: PINHD-1X10; 1X10-BIG
EXP_R: PINHD-1X10; 1X10-BIG
J1: POWER_JACKPTH_LOCK; POWER_JACK_PTH_LOCK
JP1: PINHD-1X8BIG; 1X08-BIG
JP6: 10x1F-H8.5; 1X10
POWER: 8x1F-H8.5; 1X08
PWML: 8x1F-H8.5; 1X08
S1: EG1218; SWITCH-SPDT_KIT
XIO: 18x2F-H8.5; 2X18

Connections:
+3V3: POWER.4; also elsewhere on the board
+5V: JP1.1, POWER.5; also elsewhere on the board
ADC0: ADCL.1
ADC1: ADCL.2
ADC2: ADCL.3
ADC3: ADCL.4
ADC4: ADCL.5, EXP_L.5
ADC5: ADCL.6, EXP_L.6
ADC6: ADCL.7, EXP_L.7
ADC7: ADCL.8, EXP_L.8
AREF: JP6.3
CD: JP1.8
GND: EXP_L.10, EXP_R.10, J1.GND, JP1.3, JP6.4, POWER.6, POWER.7, XIO.35, XIO.36; also elsewhere on the board
PA0: XIO.3; also elsewhere on the board
PA1: XIO.4; also elsewhere on the board
PA2: XIO.5; also elsewhere on the board
PA3: XIO.6; also elsewhere on the board
PA4: XIO.7; also elsewhere on the board
PA5: XIO.8; also elsewhere on the board
PA6: XIO.9; also elsewhere on the board
PA7: XIO.10; also elsewhere on the board
PB0: JP1.7, XIO.34; also elsewhere on the board
PB1: EXP_L.3, JP1.4, XIO.33; also elsewhere on the board
PB2: EXP_L.4, JP1.6, XIO.32; also elsewhere on the board
PB3: JP1.5, XIO.31; also elsewhere on the board
PB4: JP6.8
PB5: EXP_R.8, JP6.7
PB6: EXP_R.7, JP6.6
PB7: EXP_R.6, JP6.5
PC0: XIO.18; also elsewhere on the board
PC1: XIO.17; also elsewhere on the board
PC2: XIO.16; also elsewhere on the board
PC3: XIO.15; also elsewhere on the board
PC4: XIO.14; also elsewhere on the board
PC5: XIO.13; also elsewhere on the board
PC6: XIO.12; also elsewhere on the board
PC7: XIO.11; also elsewhere on the board
PD0: COMMUNICATION.1
PD1: COMMUNICATION.2
PD7: XIO.19; also elsewhere on the board
PE0: EXP_R.2, PWML.1
PE1: EXP_R.1, PWML.2
PE3: PWML.6
PE4: PWML.3; also elsewhere on the board
PE5: PWML.4; also elsewhere on the board
PG0: XIO.22; also elsewhere on the board
PG1: XIO.21; also elsewhere on the board
PG2: XIO.20; also elsewhere on the board
PG5: PWML.5
PH3: PWML.7
PH4: PWML.8
PH5: JP6.10
PH6: EXP_R.5, JP6.9
PL0: XIO.30; also elsewhere on the board
PL1: XIO.29; also elsewhere on the board
PL2: XIO.28; also elsewhere on the board
PL3: XIO.27
PL4: XIO.26
PL5: XIO.25; also elsewhere on the board
PL6: XIO.24; also elsewhere on the board
PL7: XIO.23; also elsewhere on the board
RESET: POWER.3
RXD1: COMMUNICATION.3; also elsewhere on the board
RXD2: COMMUNICATION.5; also elsewhere on the board
RXD3: COMMUNICATION.7, EXP_L.1
SCL: EXP_R.3, JP6.1
SDA: EXP_R.4, JP6.2
TXD1: COMMUNICATION.4; also elsewhere on the board
TXD2: COMMUNICATION.6; also elsewhere on the board
TXD3: COMMUNICATION.8, EXP_L.2
VIN: POWER.8, S1.2
VSS: EXP_L.9, EXP_R.9, J1.PWR, S1.3 (S)

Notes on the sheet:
Arduino MEGA 2560
pwm
(TX0)
(RX0)
(MOSI)
(SCK)
(MISO)
ALE
SS/CS
SCK
MOSI
MISO
CLK
MicroSD Breakout
SPI
RX0
TX0
SHIFT
LATCH
OUT
SOFTSPI or I2c

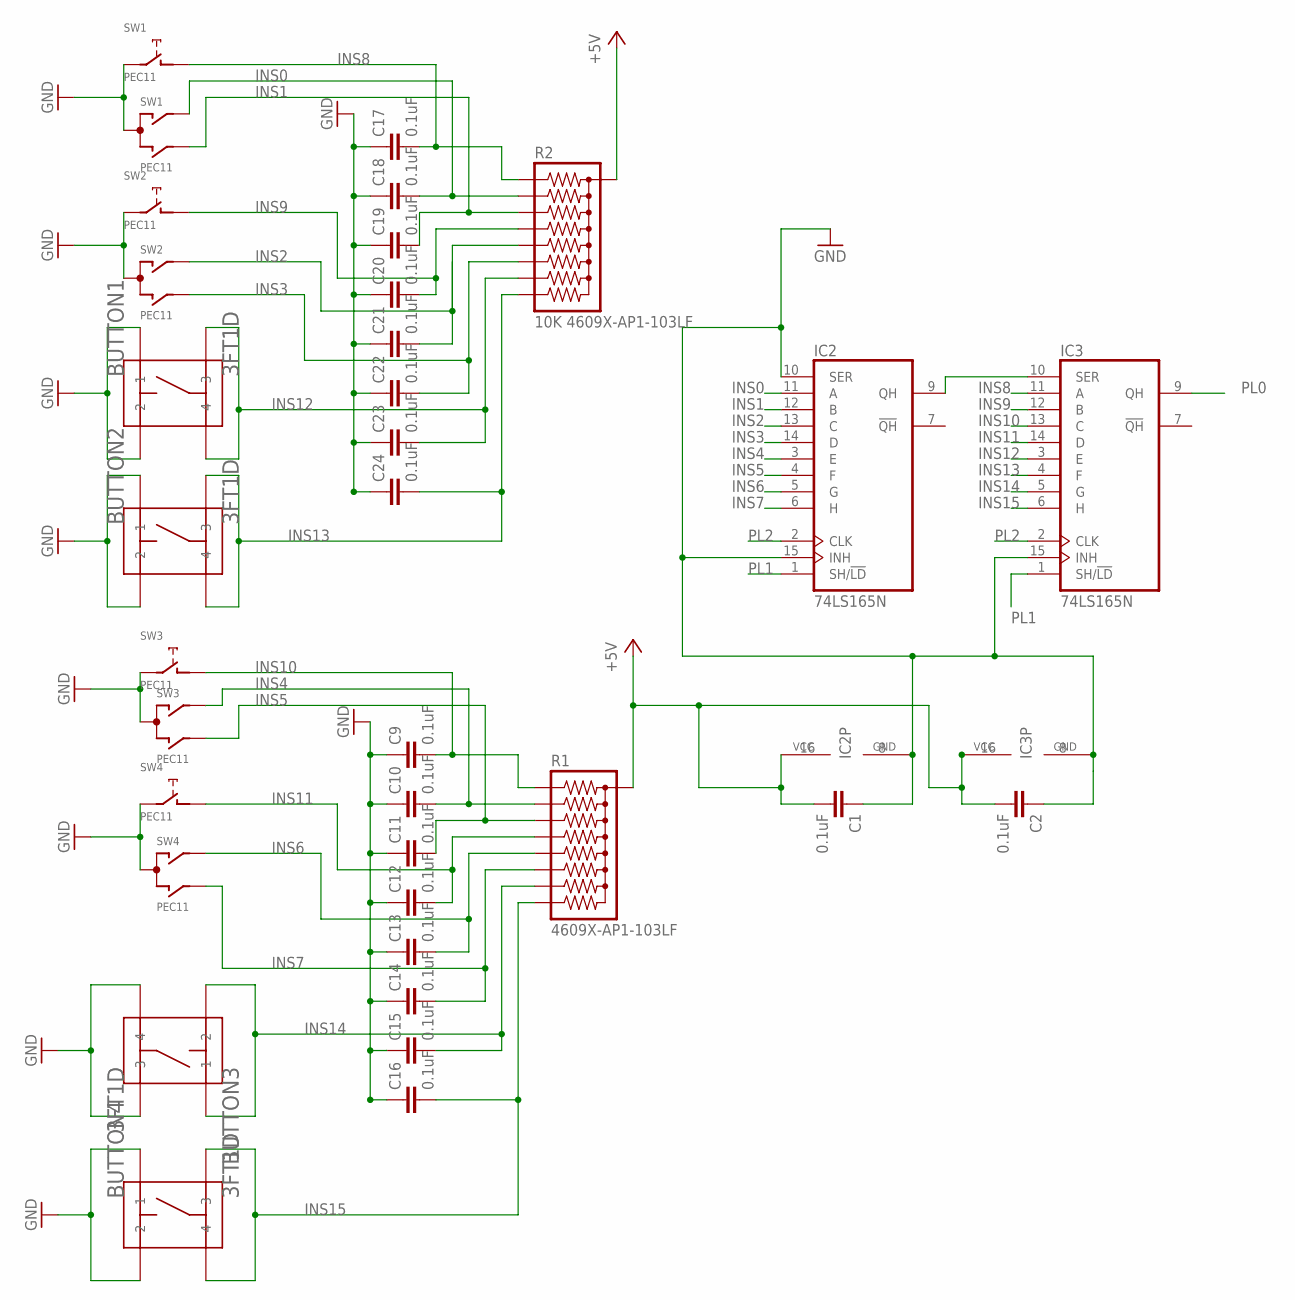
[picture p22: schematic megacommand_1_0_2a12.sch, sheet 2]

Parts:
BUTTON1, BUTTON2, BUTTON3, BUTTON4: 3FT1D; 3FT
C1, C2, C9, C10, C11, C12, C13, C14, C15, C16, C17, C18, C19, C20, C21, C22, C23, C24: 0.1uF; C025-050X050
IC2, IC3: 74LS165N; DIL16
R1: 4609X-AP1-103LF; RPACK-SIP-PTH-8
R2: 10K 4609X-AP1-103LF; RPACK-SIP-PTH-8
SW1, SW2, SW3, SW4: PEC11; ALPS_EC12E_SW

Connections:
+5V: C1.2, C2.2, IC2.16 (VCC), IC3.16 (VCC), R1.P$1 (1), R2.P$1 (1); also elsewhere on the board
GND: BUTTON1.P$1 (1), BUTTON1.P$2 (2), BUTTON2.P$1 (1), BUTTON2.P$2 (2), BUTTON3.P$3 (3), BUTTON3.P$4 (4), BUTTON4.P$1 (1), BUTTON4.P$2 (2), C1.1, C2.1, C9.1, C10.1, C11.1, C12.1, C13.1, C14.1, C15.1, C16.1, C17.1, C18.1, C19.1, C20.1, C21.1, C22.1, C23.1, C24.1, IC2.8 (GND), IC2.10 (SER), IC2.15 (INH), IC3.8 (GND), IC3.15 (INH), SW1.C, SW1.E (2), SW2.C, SW2.E (2), SW3.C, SW3.E (2), SW4.C, SW4.E (2); also elsewhere on the board
INS0: C18.2, IC2.11 (A), R2.P$3 (3), SW1.A
INS1: C19.2, IC2.12 (B), R2.P$4 (4), SW1.B
INS2: C21.2, IC2.13 (C), R2.P$6 (6), SW2.A
INS3: C22.2, IC2.14 (D), R2.P$7 (7), SW2.B
INS4: C10.2, IC2.3 (E), R1.P$3 (3), SW3.A
INS5: C11.2, IC2.4 (F), R1.P$4 (4), SW3.B
INS6: C13.2, IC2.5 (G), R1.P$6 (6), SW4.A
INS7: C14.2, IC2.6 (H), R1.P$7 (7), SW4.B
INS8: C17.2, IC3.11 (A), R2.P$2 (2), SW1.D (1)
INS9: C20.2, IC3.12 (B), R2.P$5 (5), SW2.D (1)
INS10: C9.2, IC3.13 (C), R1.P$2 (2), SW3.D (1)
INS11: C12.2, IC3.14 (D), R1.P$5 (5), SW4.D (1)
INS12: BUTTON1.P$3 (3), BUTTON1.P$4 (4), C23.2, IC3.3 (E), R2.P$8 (8)
INS13: BUTTON2.P$3 (3), BUTTON2.P$4 (4), C24.2, IC3.4 (F), R2.P$9 (9)
INS14: BUTTON3.P$1 (1), BUTTON3.P$2 (2), C15.2, IC3.5 (G), R1.P$8 (8)
INS15: BUTTON4.P$3 (3), BUTTON4.P$4 (4), C16.2, IC3.6 (H), R1.P$9 (9)
unnamed: IC2.9 (QH), IC3.10 (SER)
PL0: IC3.9 (QH); also elsewhere on the board
PL1: IC2.1 (SH/!LD), IC3.1 (SH/!LD); also elsewhere on the board
PL2: IC2.2 (CLK), IC3.2 (CLK); also elsewhere on the board

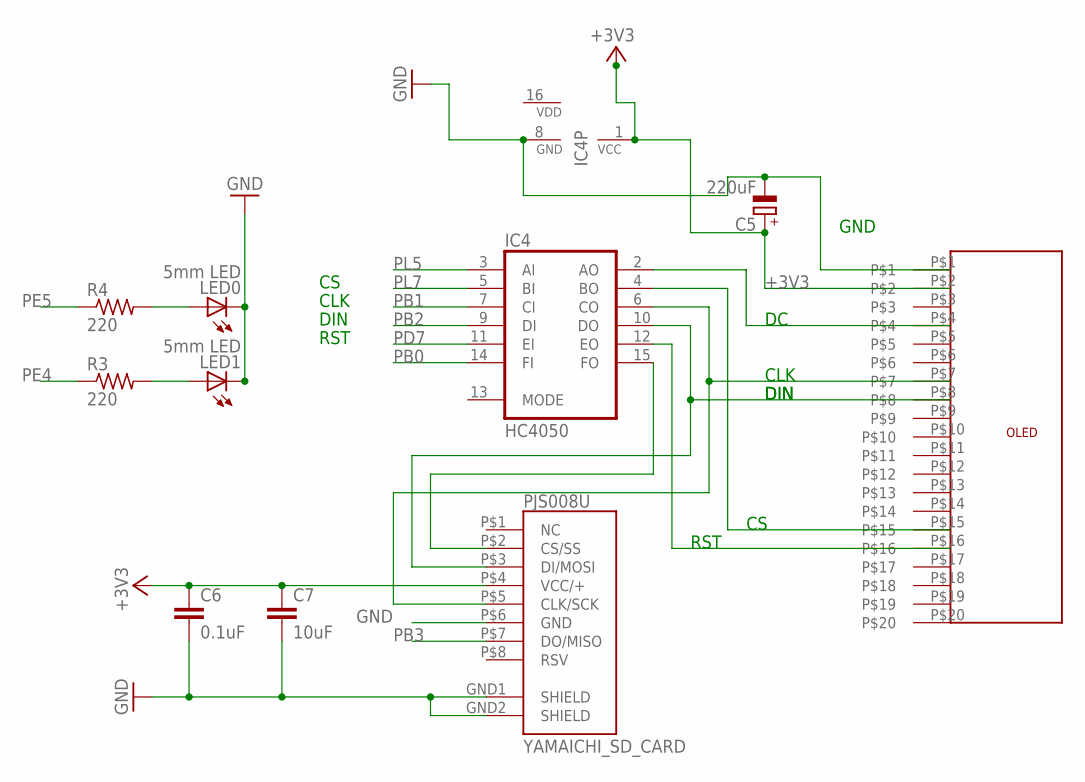
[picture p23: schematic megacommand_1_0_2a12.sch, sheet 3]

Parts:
C5: 220uF; TT2D6
C6: 0.1uF; C025-050X050
C7: 10uF; C025-050X050
IC4: HC4050; DIL16
LED0, LED1: 5mm LED; LED_LD260
PJS008U: YAMAICHI_SD_CARD; YAMAICHI_MICROSD_VERTICAL
R3, R4: 220; 0207/7
U$2: 20PIN

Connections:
+3V3: C5.+, C6.1, C7.1, IC4.1 (VCC), PJS008U.P$4 (VCC/+), U$2.P$2; also elsewhere on the board
GND: C5.-, C6.2, C7.2, IC4.8 (GND), LED0.K (C), LED1.K (C), PJS008U.GND1 (SHIELD), PJS008U.GND2 (SHIELD), PJS008U.P$6 (GND), U$2.P$1; also elsewhere on the board
unnamed: IC4.15 (FO), PJS008U.P$2 (CS/SS)
unnamed: LED0.A, R4.2
unnamed: LED1.A, R3.2
unnamed: IC4.2 (AO), U$2.P$4
unnamed: IC4.6 (CO), PJS008U.P$5 (CLK/SCK), U$2.P$7
unnamed: IC4.10 (DO), PJS008U.P$3 (DI/MOSI), U$2.P$8
unnamed: IC4.4 (BO), U$2.P$15
unnamed: IC4.12 (EO), U$2.P$16
PB0: IC4.14 (FI); also elsewhere on the board
PB1: IC4.7 (CI); also elsewhere on the board
PB2: IC4.9 (DI); also elsewhere on the board
PB3: PJS008U.P$7 (DO/MISO); also elsewhere on the board
PD7: IC4.11 (EI); also elsewhere on the board
PE4: R3.1; also elsewhere on the board
PE5: R4.1; also elsewhere on the board
PL5: IC4.3 (AI); also elsewhere on the board
PL7: IC4.5 (BI); also elsewhere on the board
VDD: IC4.16 (VDD)

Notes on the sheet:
GND
RST
CLK
DIN

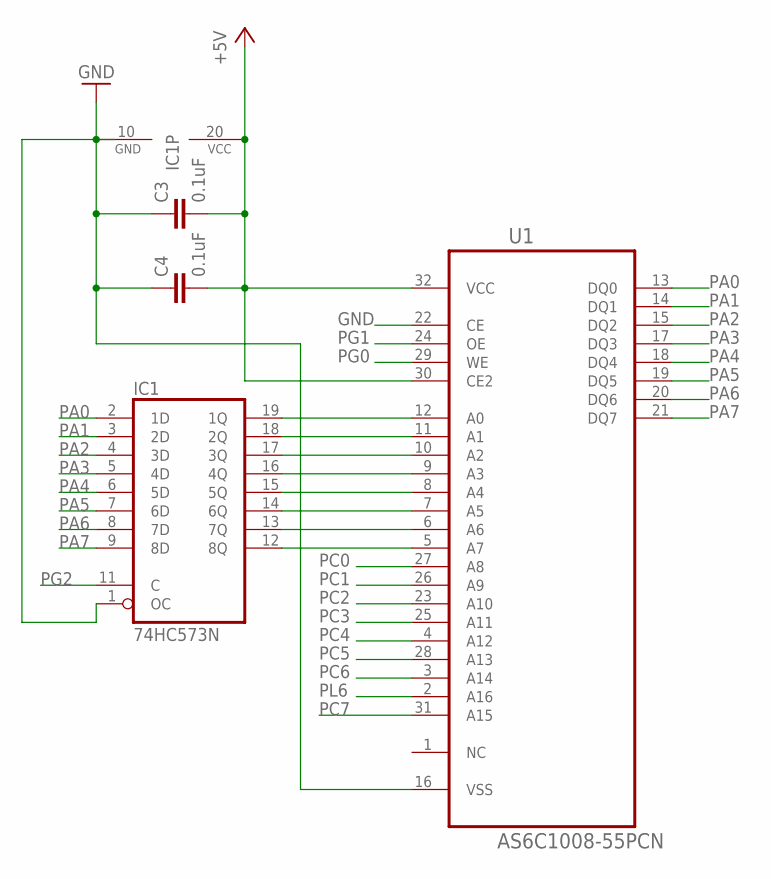
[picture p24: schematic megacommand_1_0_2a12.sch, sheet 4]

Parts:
C3, C4: 0.1uF; C025-050X050
IC1: 74HC573N; DIL20
U1: AS6C1008-55PCN; DIP254P1524X393-32

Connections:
+5V: C3.2, C4.2, IC1.20 (VCC), U1.30 (CE2), U1.32 (VCC); also elsewhere on the board
GND: C3.1, C4.1, IC1.1 (OC), IC1.10 (GND), U1.16 (VSS), U1.22 (CE); also elsewhere on the board
unnamed: IC1.13 (7Q), U1.6 (A6)
unnamed: IC1.19 (1Q), U1.12 (A0)
unnamed: IC1.18 (2Q), U1.11 (A1)
unnamed: IC1.17 (3Q), U1.10 (A2)
unnamed: IC1.16 (4Q), U1.9 (A3)
unnamed: IC1.15 (5Q), U1.8 (A4)
unnamed: IC1.14 (6Q), U1.7 (A5)
unnamed: IC1.12 (8Q), U1.5 (A7)
PA0: IC1.2 (1D), U1.13 (DQ0); also elsewhere on the board
PA1: IC1.3 (2D), U1.14 (DQ1); also elsewhere on the board
PA2: IC1.4 (3D), U1.15 (DQ2); also elsewhere on the board
PA3: IC1.5 (4D), U1.17 (DQ3); also elsewhere on the board
PA4: IC1.6 (5D), U1.18 (DQ4); also elsewhere on the board
PA5: IC1.7 (6D), U1.19 (DQ5); also elsewhere on the board
PA6: IC1.8 (7D), U1.20 (DQ6); also elsewhere on the board
PA7: IC1.9 (8D), U1.21 (DQ7); also elsewhere on the board
PC0: U1.27 (A8); also elsewhere on the board
PC1: U1.26 (A9); also elsewhere on the board
PC2: U1.23 (A10); also elsewhere on the board
PC3: U1.25 (A11); also elsewhere on the board
PC4: U1.4 (A12); also elsewhere on the board
PC5: U1.28 (A13); also elsewhere on the board
PC6: U1.3 (A14); also elsewhere on the board
PC7: U1.31 (A15); also elsewhere on the board
PG0: U1.29 (WE); also elsewhere on the board
PG1: U1.24 (OE); also elsewhere on the board
PG2: IC1.11 (C); also elsewhere on the board
PL6: U1.2 (A16); also elsewhere on the board

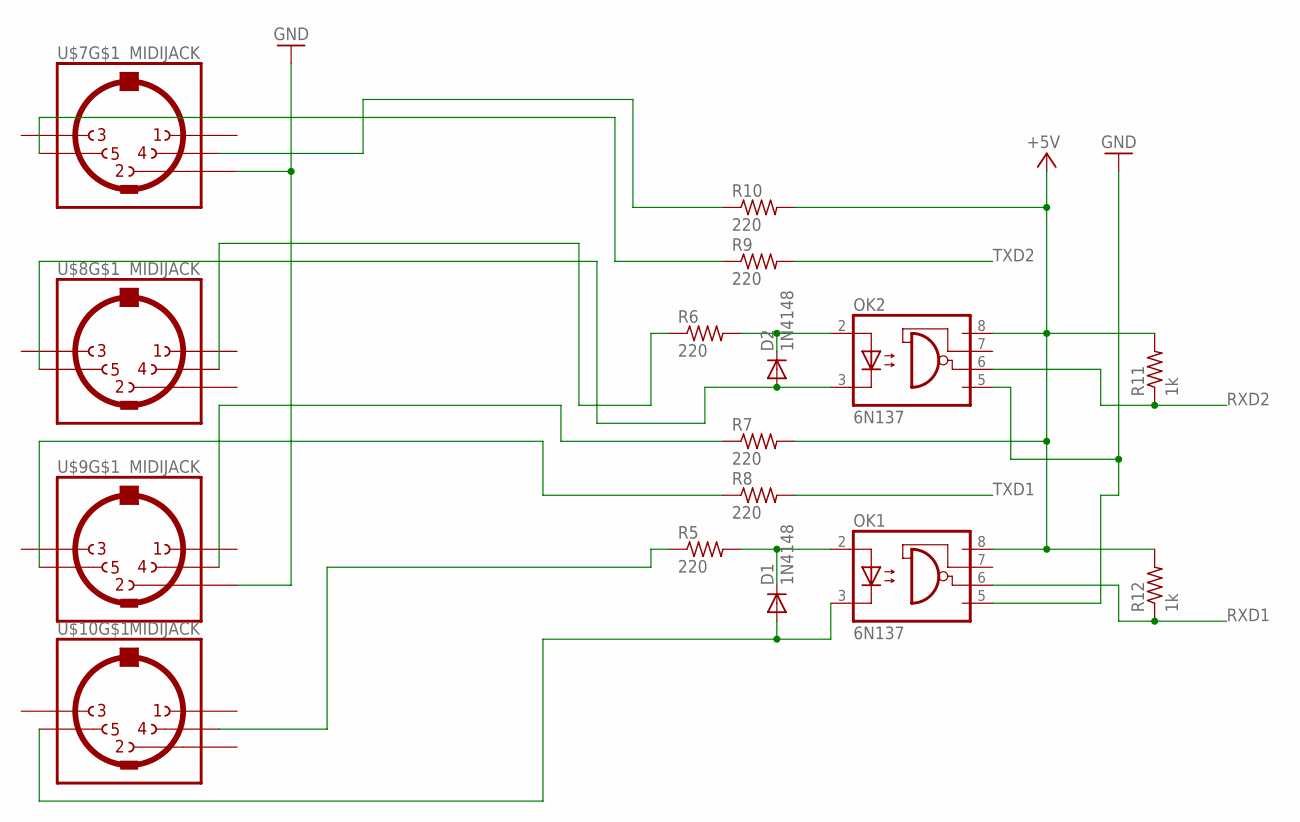
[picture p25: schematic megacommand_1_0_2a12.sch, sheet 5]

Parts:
D1, D2: 1N4148; DO35-7
OK1, OK2: 6N137; DIL08
R5, R6, R7, R8, R9, R10: 220; 0207/7
R11, R12: 1k; 0207/7
U$7, U$8, U$9, U$10: MIDIJACK; CP-2350

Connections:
+5V: OK1.8 (VCC), OK2.8 (VCC), R7.2, R10.2, R11.2, R12.2; also elsewhere on the board
GND: OK1.5 (GND), OK2.5 (GND), U$7.2, U$9.2; also elsewhere on the board
unnamed: R8.1, U$9.5
unnamed: D1.A, OK1.3 (C), U$10.5
unnamed: R5.1, U$10.4
unnamed: R7.1, U$9.4
unnamed: R10.1, U$7.4
unnamed: D2.C, OK2.2 (A), R6.2
unnamed: D2.A, OK2.3 (C), U$8.5
unnamed: R6.1, U$8.4
unnamed: R9.1, U$7.5
unnamed: D1.C, OK1.2 (A), R5.2
RXD1: OK1.6 (VO), R12.1; also elsewhere on the board
RXD2: OK2.6 (VO), R11.1; also elsewhere on the board
TXD1: R8.2; also elsewhere on the board
TXD2: R9.2; also elsewhere on the board

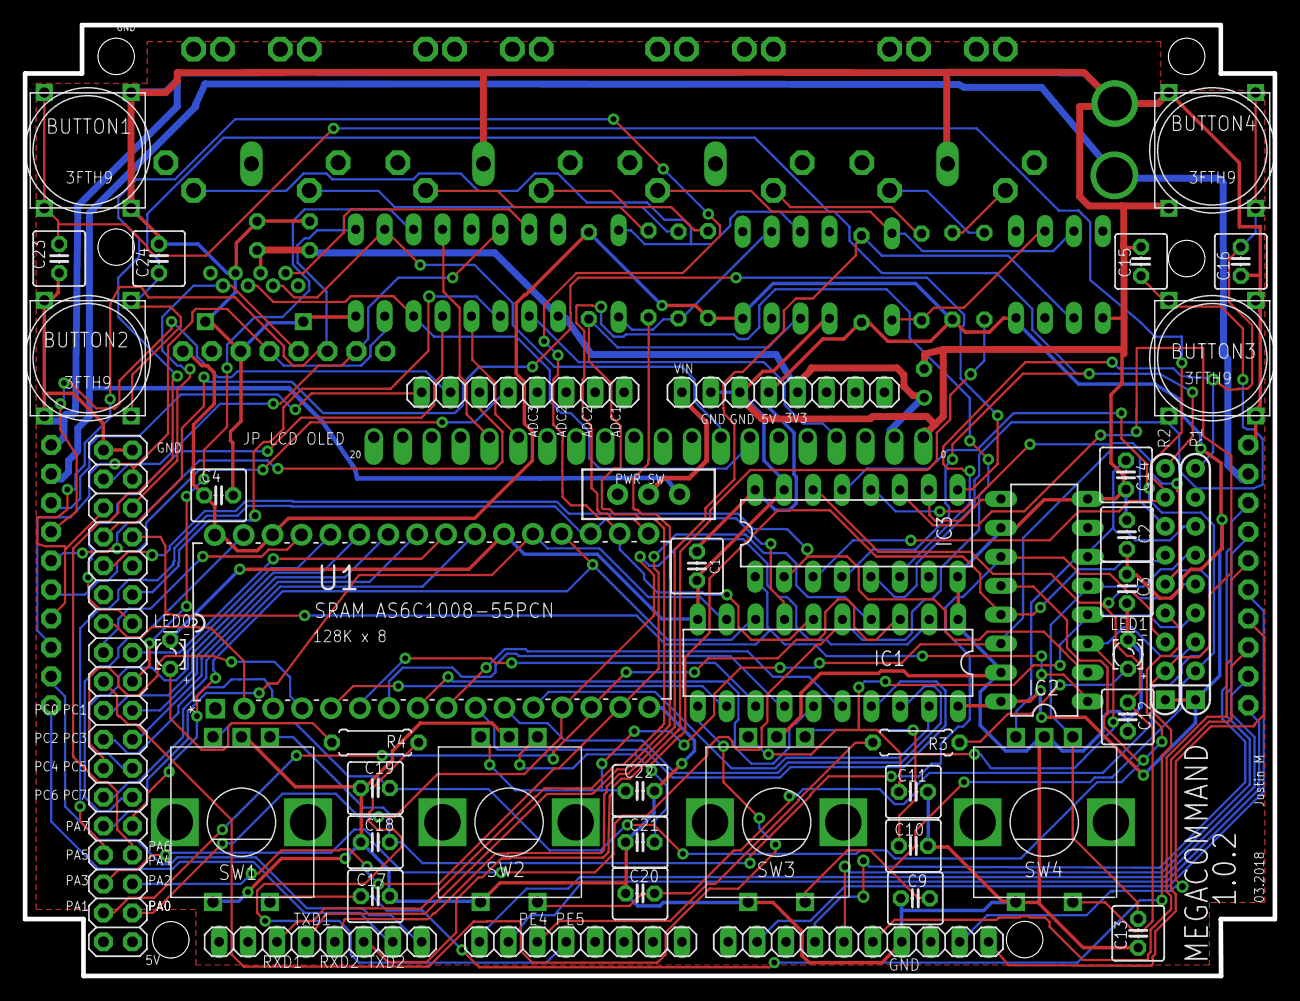
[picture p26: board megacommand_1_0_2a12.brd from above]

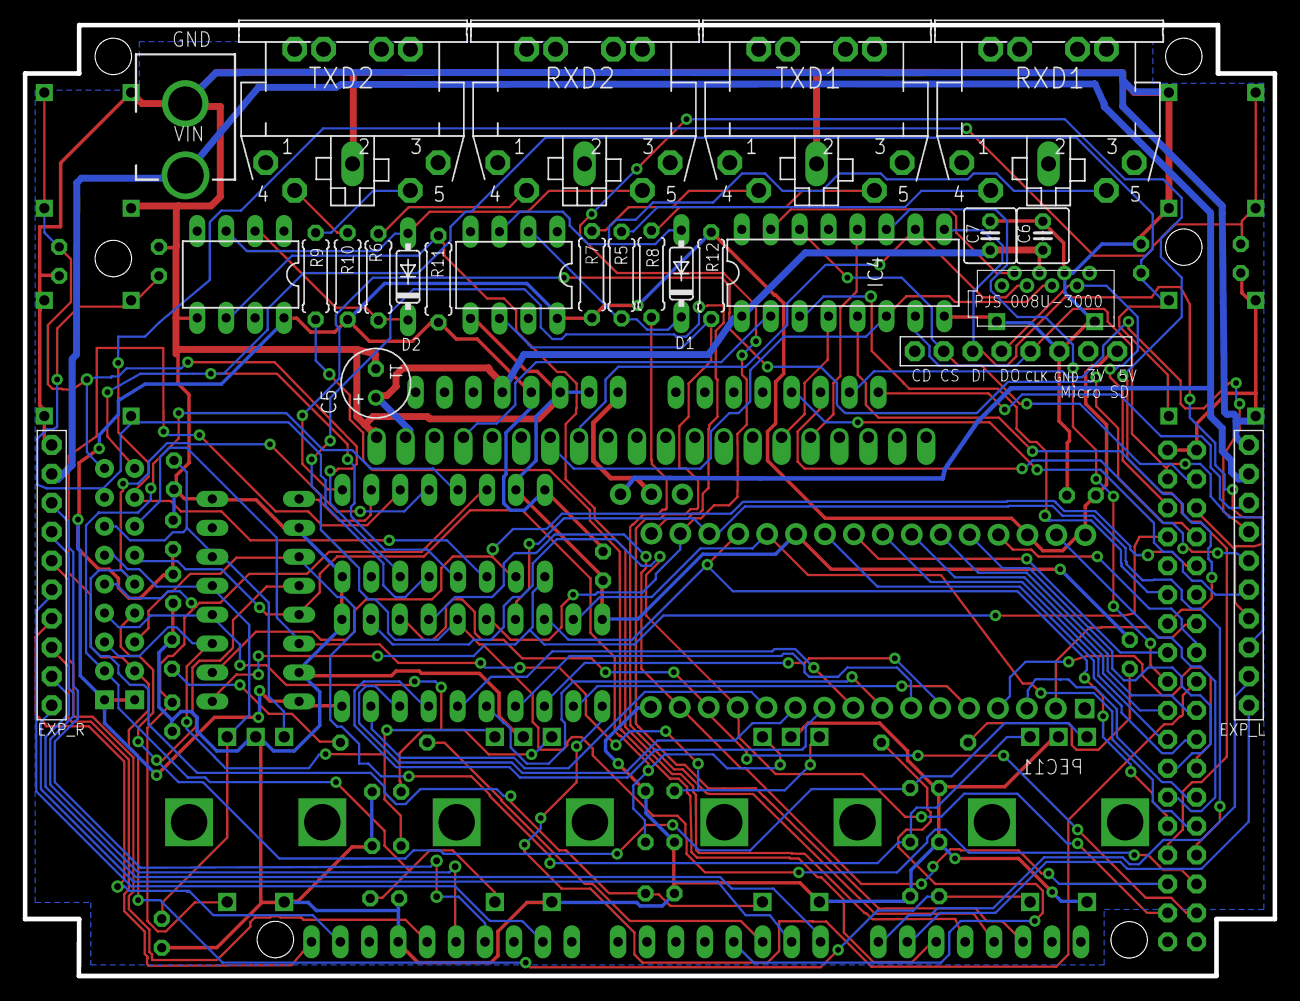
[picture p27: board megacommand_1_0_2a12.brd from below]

Board: 2 copper layers, 109.8 x 83.5 mm, 71 parts (25 on the bottom side), 98 nets.

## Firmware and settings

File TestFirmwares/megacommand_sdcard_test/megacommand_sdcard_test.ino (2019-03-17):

//MegaCommand SDCard test
//Version 1.0
//Author: Justin Mammarella
//Date: Sept 2017
//Description: Firmware to test SDCard breakout board.
//             Run this firmware by uploading to the MegaCommand. The frmware will write a file called test.txt to the SDCard.
//             View the serial monitor at 9600bps to see the test results.
//
//             An array of size ARRAY_SIZE is filled with random bytes and is written to a file called test.txt y times. Where y = WRITE_ITERATIONS
//             The file is then read back and the stored data is checked against the array.
//Notes:       This firmware uses the Arduino Core.
//             The SDCard needs to be formatted to FAT32.


#include <SD.h>
#define RANDOM_SEED 123456789
#define ARRAY_SIZE 4096
#define WRITE_ITERATIONS 256
#define BYTES ARRAY_SIZE * WRITE_ITERATIONS

File myFile;
File myFile2;

void setup()
{
  // PL7: arduino pin 42, oled CS
  pinMode(42, OUTPUT);
  digitalWrite(42, HIGH);
  
  // PB0: arduino pin 53, SS
  pinMode(53, OUTPUT);
  digitalWrite(53, HIGH);

  randomSeed(RANDOM_SEED);

  uint8_t my_array[ARRAY_SIZE];
  uint8_t random_number;
  int x, y;
  for (x = 0; x < ARRAY_SIZE; x++) {
    my_array[x] = (uint8_t) random(1, 255);
  }

  Serial.begin(9600);
  Serial.print("Initializing SD card...");

  delay(100);

  // On the Ethernet Shield, CS is pin 4. It's set as an output by default.
  // Note that even if it's not used as the CS pin, the hardware SS pin
  // (10 on most Arduino boards, 53 on the Mega) must be left as an output
  // or the SD library functions will not work.

  //delayMicroseconds(1);

  bool ret = false;

  for (uint8_t n = 0; n < 5 && ret == false; n++) {
    ret = SD.begin(53);
    if (!ret) {
      Serial.print(".");
      delay(50);
    }
  }

  if(!ret)
  {
    Serial.println("initialization failed!");
  }

  Serial.println("initialization done.");
  SD.remove("test.txt");

  unsigned long count = 0;
  uint8_t myrandom = 0;
  myFile = SD.open("test.txt", FILE_WRITE);

  // if the file opened okay, write to it:
  if (myFile) {
    Serial.println("Writing to test.txt...");
    for (y = 0; y < WRITE_ITERATIONS; y++) {
      Serial.print("Writing iteration ");
      Serial.print(y);
      Serial.println("...");
      for (int x = 0; x < ARRAY_SIZE; x++) {
        count += myFile.write(my_array[x]);
      }
    }
    myFile.close();
    Serial.print("Wrote: ");
    Serial.print(count);
    Serial.println(" bytes.");
  } else {
    // if the file didn't open, print an error:
    Serial.println("write test: error opening test.txt");
  }


  Serial.println();
  uint8_t c;
  int8_t errors = 0;
  myFile = SD.open("test.txt", FILE_READ);
  if (myFile) {
    Serial.println("Reading contents from test.txt:");

    // read from the file until there's nothing else in it:
    for (y = 0; y < WRITE_ITERATIONS; y++) {

      for (int x = 0; x < ARRAY_SIZE; x++) {
        c = myFile.read();
        if (my_array[x] != c) {
          Serial.print(my_array[x]);
          Serial.print(" ");
          Serial.println(c);
          errors += 1;
          Serial.print("Data read did not match array");
        }
      }
    }
    if (errors > 0) {
      Serial.println("SDCard test failed. Data written does not match read");
    }
    else {
      Serial.println("SDCard read data matches RAM.");
    }
    Serial.println(" ");

    Serial.print("File Size: ");

    Serial.println(myFile.size());

    Serial.print("Wrote: ");
    Serial.println(count);

    // close the file:
    if (myFile && myFile.size() !=  count) {
      Serial.println("read test: files size does not match bytes written");
    }
    else {
      Serial.println("read test Success!. Files contents matches bytes written and size matches");
    }
    myFile.close();
    
  } else {
    // if the file didn't open, print an error:
    Serial.println("read test: error opening test.txt");
  }

}

void loop()
{
  // nothing happens after setup
}

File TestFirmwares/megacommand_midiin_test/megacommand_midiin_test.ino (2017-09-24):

//MegaCommand MIDI-in test firmare.
//Version 1.0
//Author: Justin Mammarella. Based on Staffan Melin's MIDI Arduino tutorial. http://libremsicproduction.com/
//Date: Sept 2017
//Description: Firmware to test the MIDI input ports on the MegaCommand Hardware
//             Run this firmware by uploading to the MegaCommand and then sending MIDI note data to MIDI input ports 1 & 2.
//             You should see the note messages detected as indicated by the Serial Monitor output. 
//Notes:       This firmware uses the Arduino Core. Serial monitor conected at 9600bps

void setup() {
  // put your setup code here, to run once:
  Serial1.begin(31250);
  Serial2.begin(31250);

  Serial.begin(9600);
  Serial.println("MegaCommand MIDI In Test Firmware");
}
#define MIDI_NOTE_ON 144
#define MIDI_NOTE_OFF 128

const int filterChannel = 0; // MIDI channel 1
const int filterNote = 60; // middle C

// states
#define STATE_NONE 0
#define STATE_NOTE_ON 1
#define STATE_NOTE 2
#define STATE_NOTE_OFF 3

int state = 0;

// keep action (LED) going for actionDuration milliseconds
bool actionOn;
unsigned long actionTime;
unsigned long actionDuration = 100;

// received MIDI data
uint8_t serial_read;
byte channel;
byte cmd_byte;
byte midiNote;
byte midiVelocity;

void playNote(byte note, byte velocity) {
  Serial.print(note);
  Serial.println("a");
}
void printBits(byte myByte) {
  for (byte mask = 0x80; mask; mask >>= 1) {
    if (mask  & myByte)
      Serial.print('1');
    else
      Serial.print('0');
  }
}

void noteOn(int cmd, int pitch, int velocity) {
  Serial1.write(cmd);
  Serial1.write(pitch);
  Serial1.write(velocity);

}


void loop() {

  if (Serial1.available() > 0) {

    serial_read = Serial1.read();


    switch (state) {

      case STATE_NONE:

        // remove channel info
        channel = serial_read & 0x0F;
        cmd_byte = serial_read & 0xF0;

        if (cmd_byte == MIDI_NOTE_ON)
        {

          state = STATE_NOTE_ON;
        }
        if (cmd_byte == MIDI_NOTE_OFF) {
          state = STATE_NOTE_OFF;
          
        }

        //  }
        break;
    case STATE_NOTE_ON:
              Serial.println("note on port 1");

        midiNote = serial_read;
        Serial.println(midiNote, HEX);
        state = STATE_NOTE;

        break;
    case STATE_NOTE_OFF:
              Serial.println("note off port 1");

        midiNote = serial_read;
        Serial.println(midiNote, HEX);
        state = STATE_NOTE;

        break;


      case STATE_NOTE:
        midiVelocity = serial_read;
        state = STATE_NONE;
        

        if (midiNote == filterNote && midiVelocity > 0)
        {
          actionTime = millis();
          actionOn = true;
        }

        break;

    } // switch

  }
   if (Serial2.available() > 0) {

    serial_read = Serial2.read();


    switch (state) {

      case STATE_NONE:

        // remove channel info
        channel = serial_read & 0x0F;
        cmd_byte = serial_read & 0xF0;

        if (cmd_byte == MIDI_NOTE_ON)
        {

          state = STATE_NOTE_ON;
        }
        if (cmd_byte == MIDI_NOTE_OFF) {
          state = STATE_NOTE_OFF;
          
        }

        //  }
        break;
    case STATE_NOTE_ON:
              Serial.println("note on port 2");

        midiNote = serial_read;
        Serial.println(midiNote, HEX);
        state = STATE_NOTE;

        break;
    case STATE_NOTE_OFF:
              Serial.println("note off port 2");

        midiNote = serial_read;
        Serial.println(midiNote, HEX);
        state = STATE_NOTE;

        break;


      case STATE_NOTE:
        midiVelocity = serial_read;
        state = STATE_NONE;
        

        if (midiNote == filterNote && midiVelocity > 0)
        {
          actionTime = millis();
          actionOn = true;
        }

        break;

    } // switch

  }

}

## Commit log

2017-03-06 Adding files
    [megacommand16.brd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]
2017-03-23 3D Models of the 1590BB enclosuer with machining
    [megacommand_body_1_0_0b.stl, megacommand_lid_1_0_0b.stl]
2017-03-26 Enclosure modified for correct midi port placement. Material now also removed from lid. I've updated the eagle files for the new LCD placement. Pad size increased for encoders. Some capactiors moved 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
    [megacommand18.brd, megacommand18.sch, megacommand_body_1_0_0cx.stl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]
2017-04-02 MegaCommand 1.0.0c Gerber
    [megacommand.GBL, megacommand.GBO, megacommand.GBS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]
2017-04-02 PCBWay fabrication preferences. Use these settings to fab your own boards
2017-04-02 MegaCommand 1_0_0c 3D models for printing or milling
    [megacommand_body_1_0_0c.obj, megacommand_body_1_0_0c.stl, megacommand_lid_1_0_0c.stl]
2017-04-02 MegaCommand 1_0_0c board and schematic files
    [megacommand21.brd, megacommand21.sch, test3.stl]
2017-04-02 Removing old files
    [megacommand16.brd, megacommand16.sch, megacommand18.brd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]
2017-04-02 MegaCommand Lid 1_0_0c
    [megacommand_lid_1_0_0c.FCStd]
2017-04-03 bill of materials
2017-04-28 This revision includes an OLED Header and Level Shifter, the powerjack component has been replcaed as the pcbfootprint was incorrect
    [megacommand23-oledpowerfix.brd, megacommand23-oledpowerfix.sch]
2017-05-06 Midi port size increased
    [megacommand_body_1_0_0d_obj.stl, megacommand_lid_1_0_0d-2.stl]
2017-06-06 MegaCommand 1.0.1 . OLED added. Led position shifted. New footprint for DC jack. Complete re-route.
    [megacommand24.brd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]
2017-06-07 Fix for GND rail
    [megacommand24.brd]
2017-06-26 cleanup 2
    [megacommand_body_1_0_0c.obj, megacommand_body_1_0_0c.stl, megacommand_body_1_0_0cx1.FCStd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]
2017-07-12 MegaCommand 1_0_1a Schematics + Gerbers. Correct OLED display port direction and added a 12bit SPI DAC
    [megacommand27.brd, megacommand27.sch]
2017-09-19 created gerber directory
2017-09-24 Added button_and_encoder test firmware
2018-02-23 Bug fix, would try to read memory location above 0xFFFF and fail
    [megacommand_sram_test.ino]
2018-04-20 Added eagle schematic and board for 1.0.2a11
    [megacommand_1_0_2a11.brd, megacommand_1_0_2a11.sch]
2018-04-23 Added 1_0_2_a12 gerbers
2018-04-23 DC jack was on wrong side of board
    [megacommand_1_0_2a12.brd, megacommand_1_0_2a12.sch]
2018-04-23 remove old files
    [megacommand_1_0_2a11.brd, megacommand_1_0_2a11.sch]
2019-03-12 directory restructure
    [megacommand_1_0_1a.brd, megacommand_1_0_1a.sch, megacommand_1_0_2a12.brd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]
2019-03-12 Added OLED enclosure design (thanks to Ozone)
    [megacommand_body_1_0_0d.FCStd, megacommand_body_1_0_0d_obj.stl, megacommand_body_1_0_2d_v2.FCStd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]
2019-03-16 TestFirmwares: sdcard test: fix initialization sequence
    [megacommand_sdcard_test.ino]
2019-04-02 add expansion port pin diagram
2019-04-09 Regenerated enclosure body in freecad.
    Had to turn the 590BB enclosure in to a "Solid" object before
    performing boolean cut operations.
    Regenerate the mesh STL. The 3D slicer is reporting 0 issues,
    which is a massive improvement.
    [megacommand_body_1_0_2d_v2.FCStd, megacommand_body_1_0_2d_v2.stl]
2019-04-09 Added M3 square nut traps traps to the enclosure design
2019-04-10 Reduced OLED width slightly, created a taller version of the original model. Need to test both
    [megacommand_body_1_0_2d_v2.FCStd, megacommand_body_1_0_2d_v2.stl]
2019-04-10 Update lid for tall model
    [megacommand_lid_1_0_2d-tall.FCStd]
2019-04-11 Increased trap height to 2mm, increased drill hole size, reduced body height by 2mm (Tall)
2019-04-14 Update lid, for tall enclosure. Has raised support for MIDI ports
    [megacommand_lid_1_0_2d-tall.FCStd]
2019-04-15 Removed nut traps, reverted screw size, reduced LED size, re-organised dir
    [megacommand_body_1_0_2d_v2.FCStd, megacommand_body_1_0_2d_v2.stl, megacommand_lid_1_0_0d-2.stl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]
2019-04-15 Drill hole radius consistant along depth
2019-04-16 Added printable encoder knobs
    [encoder.FCStd, encoder.stl]
2019-04-16 Rounded upper edge of encoder
    [encoder.FCStd, encoder.stl]
2019-04-19 Move lower buttons up by 0.5mm to match 1_0_2 board layout
2019-04-22 fix drill hole radius inconsistency along depth
2019-08-14 add assembled board model
    [BOM_1_0_2a11.xlsx]
2019-08-14 add assembled board model with arduino
2019-10-12 fix oled module dimensions, add other part STL models
    [0207_7_0207_7.STL, alps_encoder.STL, oled_2.STL]
2020-04-25 Update BOM_1_0_2a11
    update switch part number.
2020-08-14 Update megacommmand lid with shorter rise
    [megacommand_lid_1_0_2d-tall.FCStd, megacommand_lid_1_0_2d-tall_small_rise.stl]
2020-08-14 Remove old lid stl
2021-04-22 Improve BOM
    [BOM_1_0_2a11.xlsx]
2021-04-22 rm 1_0_1
    [megacommand_1_0_1a.brd, megacommand_1_0_1a.sch]
2021-09-09 Add additional testing stage to detect addressing problems
    [megacommand_sram_test.ino]
2021-11-30 Add spacers for the OLED screen
    [oled_spacer.stl]
2023-04-16 Add files via upload
    Files from Marcus B.
    [MG_body.stl, MG_panel.stl]
2023-05-01 Add MegaCMD non-diy enclosure stl files
    [megacmd_body.stl, megacmd_lid.stl]
2023-05-01 Add Pabloantxon designs
    [ArduinoStand.stl, BoxCorner.stl, knob.stl]
2023-05-01 folder renaming
    [ArduinoStand.stl, BoxCorner.stl, MG_body.stl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]

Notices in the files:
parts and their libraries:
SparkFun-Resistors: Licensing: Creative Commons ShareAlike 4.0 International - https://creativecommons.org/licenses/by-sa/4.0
